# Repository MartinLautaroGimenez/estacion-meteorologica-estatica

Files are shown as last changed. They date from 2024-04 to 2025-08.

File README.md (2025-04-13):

# Estación Meteorológica Fija
## ¿Qué es una estación meteorológica?
Una estación meteorológica es un dispositivo tecnológico de características electrónica e informática que permite nuclear parámetros relevantes para realizar estudios y sacar conclusiones frente a fenómenos físicos.

## ¿Qué es E.M.F.?
Este es el inicio del proyecto EME, fue desarrollado en 2022 por el Alumno Nicolas Pérez de la escuela ETec UM, para posteriormente en el año 2024, tras el egreso de Nicolas de la escuela, la estación fue acogida por el taller Aeroglobe ETec y en conjunto con el nevo equipo que se creó en el taller se le pudo dar continuidad y agregar sensores y actualizar partes de la estación. 

## E.M.E.
Este es un proyecto institucional y surge de la necesidad de poder comprar los sistemas atmosféricos de algunos departamentos como Godoy Cruz, Gran Mendoza, Lavalle entre otros departamentos unidos a la red de la Escuela ETec de la Universidad de Mendoza para tener un conocimiento amplio de las condiciones atmosféricas de la provincia y así contribuir al análisis de las condiciones climáticas de la misma. Este es el nexo entre todas las estaciones y su finalidad es crear una red de nodos open surce en la cual podamos extraer datos para diferentes investigaciones o proyectos ya sean de la escuela o externos ya que los datos son públicos.  

## Los modulos incorporados
  - [ESP32](#ESP32)
  - [BMP180](#BMP180)
  - [DHT22](#DHT22)
  - [BMS 3S](#BMS-3S)
  - [Baterías 18650](#Baterías-18650)
  - [Panel Solar](#Panel-Solar)
  - [Sensor de Hoja Mojada](#Sensor-de-Hoja-Mojada)
  - [BH1750](#BH1750)
  - [MQ-135](#MQ-135)
  - [Veleta](#Veleta)
  - [Anemómetro](#Anemómetro)
 
### ESP32
#### DOIT ESP32 Devkit V1
La placa ESP32 (DOIT ESP32 Devkit V1) es un módulo basado en el microcontrolador ESP32, conocido por su capacidad de conexión Wi-Fi y Bluetooth. En nuestra estación meteorológica, esta placa desempeñará un papel vital al ofrecer una base solida para la  recopilación y transmisión de datos ambientales. Con su capacidad para manejar múltiples sensores y su compatibilidad con entornos de desarrollo como Arduino IDE, la ESP32 garantiza un funcionamiento continuo incluso en condiciones adversas, asegurando la integridad y precisión de las mediciones meteorológicas.

<div align="center">
   
</div>

### BMP180
El sensor BMP180 es un dispositivo el cual es utilizado para medir la presión atmosférica y la altitud a nivel del mar con un alto nivel de precisión. Es conocido por su pequeño tamaño y por su simplicidad al momento de realizar mediciones. 

<div align="center">
   
</div>

### DHT22
El sensor DHT22 es un componente crucial en el campo de la electrónica y la monitorización ambiental. 
Su función principal es medir con precisión la temperatura ambiente y la humedad relativa del entorno en el que se encuentra la estación meteorológica. Este sensor incorpora un termistor para la medición de la temperatura y un elemento especializado para medir la humedad relativa.

<div align="center">
   
</div>

### BMS 3S
El módulo BMS 3S es esencial para la carga de las baterías, ya que desempeña un papel crucial en la regulación del voltaje que reciben durante el proceso de carga. Este módulo garantiza que las baterías reciban el voltaje adecuado para una carga segura y eficiente.

<div align="center">
   
</div>

### Baterías 18650
Las baterías 18650 son células recargables de iones de litio conocidas por su alta densidad de energía y fiabilidad. En nuestra estación meteorológica, estas baterías desempeñarán un papel vital al ofrecer una fuente de alimentación constante y duradera, lo que garantizará un funcionamiento continuo incluso en condiciones adversas en las que el panel solar no pueda suministrar la potencia nominal.

<div align="center">
   
</div>

### Panel Solar
El panel solar le da la capacidad de poder estar lejos en un sector en donde no sea posible el tendido eléctrico para la alimentación de la EME, además brinda una opción de energía sustentable y limpia, reduciendo así el consumo eléctrico convencional que mayoritariamente proviene de centrales térmicas.
Además el mismo se le incorpora un pequeño módulo regulador de tensión para poder adaptar los niveles de tensión requeridos para la lógica del microcontrolador.

<div align="center">
   
</div>

### Sensor de Hoja Mojada
El sensor de hoja mojada permite tomar cómo parámetro el estado de la planta en cuanto a la generación de microorganismos que se presenten en la planta, de está manera se puede regular la aplicación de insecticida sin sobredosificar y ahorrando cantidades del mismo, si el mismo fuese aplicado a calendario. Además permite tener un mejor control en cuanto a la biodiversidad de los demás microorganismos que puedan aparecer en la planta que no sean dañinos. 

<div align="center">
   
</div>

### BH1750
El sensor BH1750 es un sensor el cual está diseñado para medir la intensidad de la luz de manera precisa. Es altamente valorado por su facilidad de uso y su capacidad de obtener lecturas rápidas en una amplia variedad de ambientes. Su pequeño tamaño y alta precisión lo hacen el más querido de los sensores de luz.

<div align="center">
   
</div>

### MQ-135
El sensor MQ135 es un componente el cual permite detectar gases nocivos para el aire, como el amoníaco, sulfuro de hidrógeno, dióxido de carbono, y otros compuestos orgánicos volátiles. Es conocido por la capacidad de proporcionar alertas tempranas sobre la presencia de estos gases.
De este sensor podemos tomar datos analógicos del comportamiento de la mezcla de gases y la capacidad de marcar un umbral de disparo para una salida digital de ser requerida, para ello es necesario acceder manualmente al trimmer de su pcb y calibrar el disparo del mismo

<div align="center">
   
</div>

### Veleta
Permite tomar la dirección actual del viento discretizando dicha dirección en 8 posiciones cardinales gracias a su forma constructiva, un imán de neodimio y 8 reed switch.

<div align="center">
     
</div>

### Anemómetro 
Para el anemómetro se requiere tanto de la parte física como del módulo o sensor de efecto hall que es quien detecta cada revolución de giro y la envía a una etapa amplificadora para poder contar cada pulso entrante 

<div align="center">
    
</div>

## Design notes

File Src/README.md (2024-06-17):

# Código Fuente (SRC)

Parte encargada del funcionamiento del sistema embebido que es la estación meteorológica estática (EME) de por si, en donde se ha optado por usar un ESP32 en su placa de desarrollo DOIT ESP32 DevKit V1 programando en el entorno de VSCode con el plugin de PlatformIO y haciendo uso del framework de Arduino para su programación

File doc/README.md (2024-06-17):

# Documentación 

Apartado para el agregado de documentación pertinente tales cómo, informe técnico, hojas de datos relevantes, manual de uso del proyecto, flyer paso a paso de su uso o similares.

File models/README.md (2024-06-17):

# Modelos 3D

Actualmente se trabajado con SolidWorks y Fusion360 para el diseño de los mismos. Además de considerar modelos ya existentes en la red de Thingiverse de la cual nos hemos basado.

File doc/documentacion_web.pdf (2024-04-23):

# EME

# DOCUMENTACIÓN

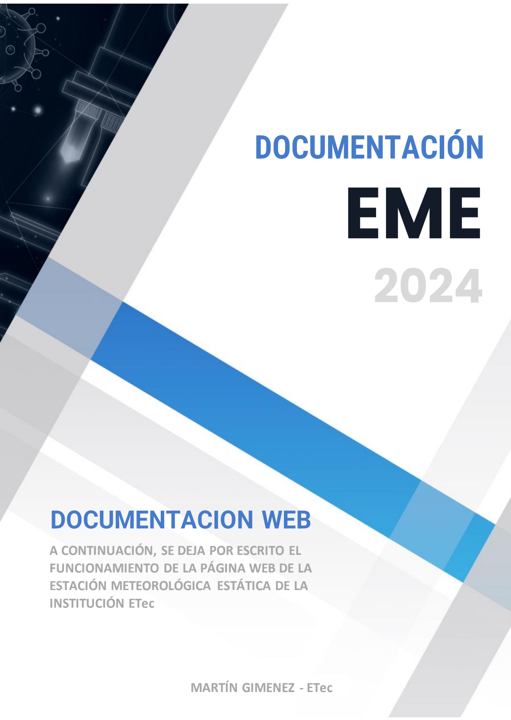
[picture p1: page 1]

# DOCUMENTACION WEB

### A CONTINUACIÓN, SE DEJA POR ESCRITO EL FUNCIONAMIENTO DE LA PÁGINA WEB DE LA ESTACIÓN METEOROLÓGICA ESTÁTICA DE LA INSTITUCIÓN ETec

2024

### MARTÍN GIMENEZ - ETec

El proyecto consiste en una aplicación web de una estación meteorológica que consta de tres archivos principales: index.html, style.css y app.js. A continuación se detalla el funcionamiento y los principios básicos de cada uno.
Index.html
El archivo index.html es la página principal de la aplicación. A continuación se describe su contenido y funcionalidad:
- Doctype y etiquetas HTML: El documento comienza con la declaración ‘<!DOCTYPE html>’ que es una instrucción para el navegador web sobre la versión de HTML que el documento está usando. Luego, el documento HTML se envuelve con la etiqueta <html> y se especifica el idioma del documento como español con el atributo lang="ES".
- Head: Dentro de la etiqueta <head>, se definen varios metadatos para el documento HTML. Esto incluye la codificación de caracteres, la configuración de la vista del puerto para dispositivos móviles, el título de la página y las referencias a los archivos de estilo CSS y a los iconos de la página.
- Body: El cuerpo del documento HTML contiene el contenido principal de la página web. Se divide en varias secciones:
- Sección de Datos Básicos: Esta sección muestra los datos meteorológicos básicos como la temperatura, la humedad, la presión atmosférica y la última actualización. Los datos se actualizan dinámicamente utilizando JavaScript.
- Tabla de Datos: Esta tabla muestra una lista de lecturas meteorológicas recientes. Los datos se insertan dinámicamente en la tabla utilizando JavaScript.
- Gráfico: Esta sección contiene un elemento de canvas para un gráfico para visualizar los datos meteorológicos y botones para ajustar la escala del gráfico.
- Pie de página: El pie de página contiene notas y descriptores sobre el proyecto, así como enlaces a la página de GitHub del proyecto y a una función para exportar los datos a Excel.
- JavaScript: Al final del cuerpo del documento, hay un bloque de código JavaScript que utiliza la API Fetch para obtener los últimos datos meteorológicos de un servidor local en http://localhost:3000/ultimos-datos. Los datos obtenidos se utilizan para actualizar el contenido de la página y para insertar filas en la tabla de datos.
STYLE.CSS
Brevemente explicando el funcionamiento de este archivo es el encargado de brindarle los estilos de la página web a index.html

APP.JS
Introducción
El archivo `app.js` es un script de Node.js que utiliza el marco de trabajo Express.js para crear un servidor web. Este servidor se conecta a una base de datos MySQL y proporciona una interfaz de API para interactuar con los datos. También utiliza el middleware CORS para permitir solicitudes de origen cruzado.
Importación de módulos

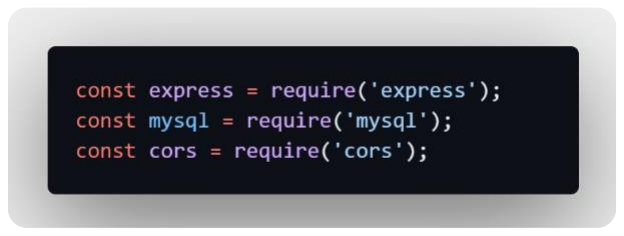
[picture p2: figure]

El script comienza importando los módulos necesarios. `express` es un marco de trabajo para crear servidores web en Node.js, `mysql` es un módulo para interactuar con bases de datos MySQL y `cors` es un middleware para habilitar CORS (Cross-Origin Resource Sharing).

Creación de la aplicación Express

Aquí se crea una nueva aplicación Express.

Configuración de la base de datos

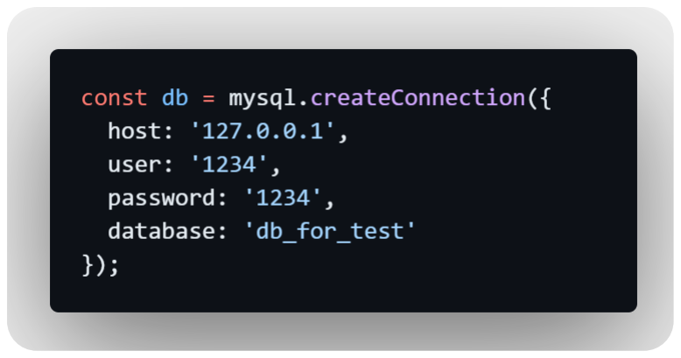
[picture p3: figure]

Se crea una conexión a la base de datos MySQL utilizando el método `createConnection` del módulo `mysql`. Los detalles de la conexión se proporcionan como un objeto.

Conexión a la base de datos

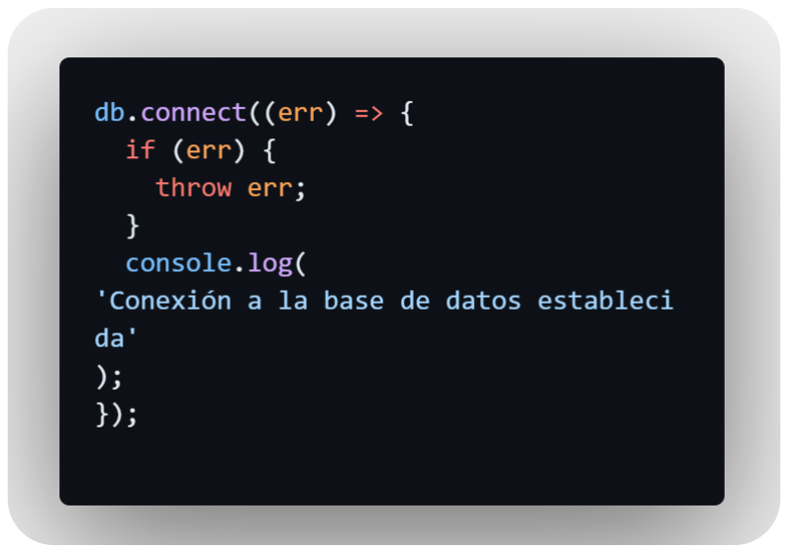
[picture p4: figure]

Se establece la conexión a la base de datos. Si hay un error durante la conexión, se lanzará una excepción.

Configuración de CORS

Se configura el middleware CORS en la aplicación Express para permitir solicitudes de origen cruzado.

Rutas de la API

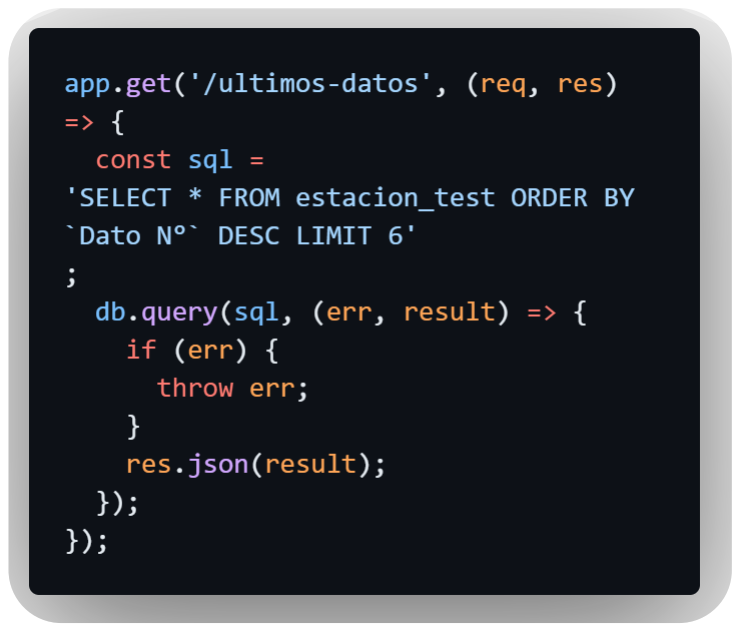
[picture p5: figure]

Se define una ruta de API para obtener los últimos datos de la base de datos. La consulta SQL selecciona los últimos 6 registros de la tabla `estacion_test`.

Servir archivos estáticos

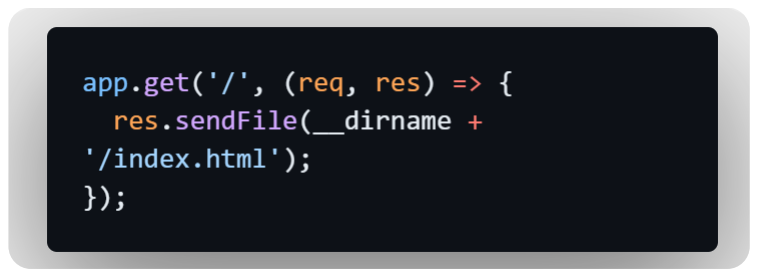
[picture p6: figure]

Se define una ruta para servir el archivo `index.html` cuando se accede a la raíz del servidor.

Inicio del servidor

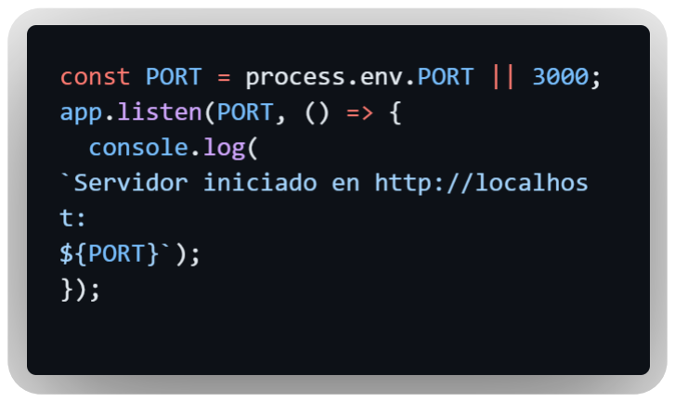
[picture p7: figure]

Finalmente, el servidor se inicia en el puerto especificado por la variable de entorno `PORT` o, si no está definida, en el puerto 3000.
CONCLUSIÓN

La documentación proporcionada detalla de manera clara y concisa el funcionamiento y los principios básicos del proyecto de la estación meteorológica. Desde la estructura de los archivos principales hasta los detalles de implementación en app.js, cada componente está explicado con suficiente detalle para comprender su propósito y funcionamiento.
La inclusión de imágenes ilustrativas mejora aún más la comprensión visual de la estructura del proyecto y la relación entre sus componentes. Esto facilita tanto el entendimiento inicial del proyecto como su mantenimiento continuo y la realización de contribuciones por parte de otros desarrolladores.
En resumen, la documentación proporcionada sirve como una guía completa y accesible para cualquier persona interesada en comprender, utilizar o contribuir al proyecto de la estación meteorológica.

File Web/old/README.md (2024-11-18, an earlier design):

# WEB DEVELOP

## Funcionalidades
La idea de poder tener una estación operativa que pueda leer datos es buena idea, pero si no son accesibles, dificílmente puedan ser aprobechables, por lo que se piensa armar una interfaz de usuario (Dashboard) capaz de poder proveer de dichos datos de interes a quienes lo soliciten o corresponda.

## ¿Qué se tiene en EMETec?
Cómo se ha visto un poco sobre la idea anteriormente, se proveeran datos de humedad relativa, temperatura absoluta, sensación térmica, temperatura punto de rocio, presión absoluta, presión a nivel de mar, altitud, intensidad luminica, valocidad del viento, dirección del mismo, calidad de aire, partes por millón de CO2, humedad de suelo y lluvia entre otros posibles datos de interes que vayan agregandosé en cada actualización.
<div align="center">
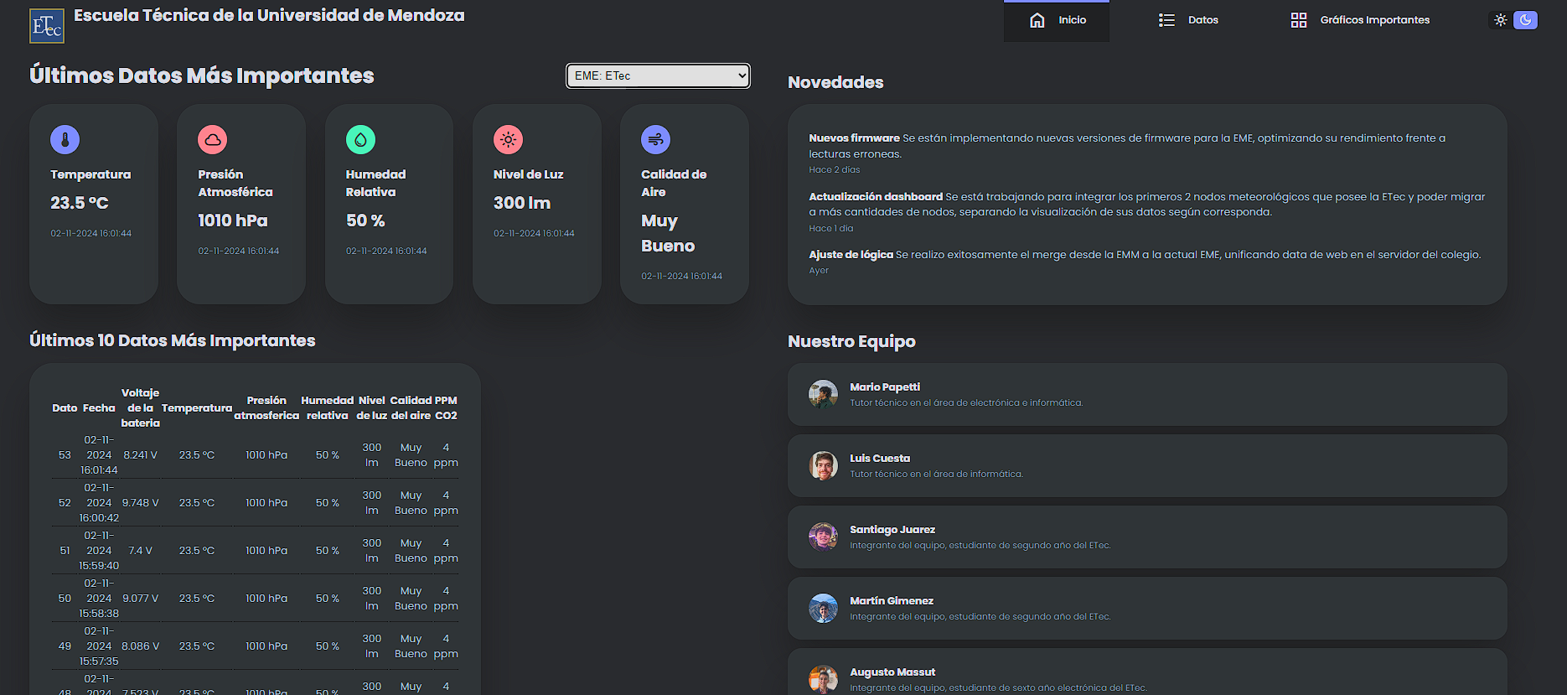
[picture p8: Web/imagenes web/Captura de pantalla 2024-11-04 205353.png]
   
</div>
## Las partes del Dashboard

  - [Dashboard](#Dashboard)
  - [Datos](#Datos)
  - [Gráficos](#Gráficos)
  - [Información](#Información)

### Dashboard
#### Dashboard Principal
El Dashboard Principal muestra una visión general de todos los datos recolectados por la estación meteorológica. Aquí, los usuarios pueden ver gráficos en tiempo real de las mediciones actuales, así como acceder a datos históricos. La interfaz está diseñada para ser intuitiva y fácil de usar, permitiendo a los usuarios personalizar las vistas según sus necesidades específicas. Además, se incluyen alertas y notificaciones para eventos meteorológicos importantes, asegurando que los usuarios estén siempre informados de las condiciones climáticas relevantes.

### Datos
#### Datos en Tiempo Real
En esta sección, los usuarios pueden acceder a los últimos datos proporcionados por la estación meteorológica. Los datos se actualizan cada 15 minutos para reflejar las condiciones actuales. Los usuarios pueden ver información detallada sobre cada parámetro medido, como temperatura, humedad, presión, y más.

#### Exportación de Datos
Los usuarios tienen la opción de exportar los datos en formato XLSX (Microsoft Excel), para su análisis externo. Esta funcionalidad permite a los usuarios integrar los datos de la estación meteorológica con otras herramientas y plataformas de análisis de datos.

### Gráficos
Sección que se lanzará proximamente.
#### Gráficos Personalizados
Esta sección permitirá a los usuarios crear gráficos personalizados basados en los datos recolectados por la estación meteorológica. Los usuarios podrán seleccionar los parámetros que desean visualizar y ajustar el rango de fechas para analizar tendencias específicas. Esta funcionalidad estará disponible próximamente.

#### Gráficos Comparativos
Próximamente, los usuarios podrán comparar diferentes parámetros meteorológicos en un solo gráfico. Esta herramienta será útil para identificar correlaciones y patrones entre variables como temperatura, humedad y presión.

#### Descarga de Gráficos
En una futura actualización, se habilitará la opción de descargar los gráficos en varios formatos (PNG, JPEG, PDF) para su uso en informes y presentaciones.

### Información
Proximamente

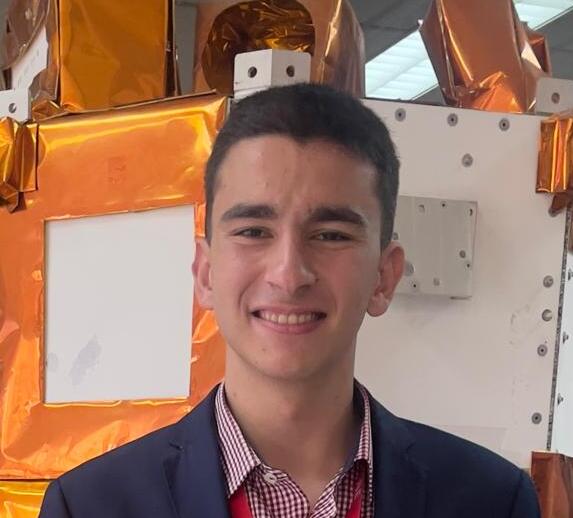
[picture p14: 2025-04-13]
Web/frontend/images/team/augusto.jpg

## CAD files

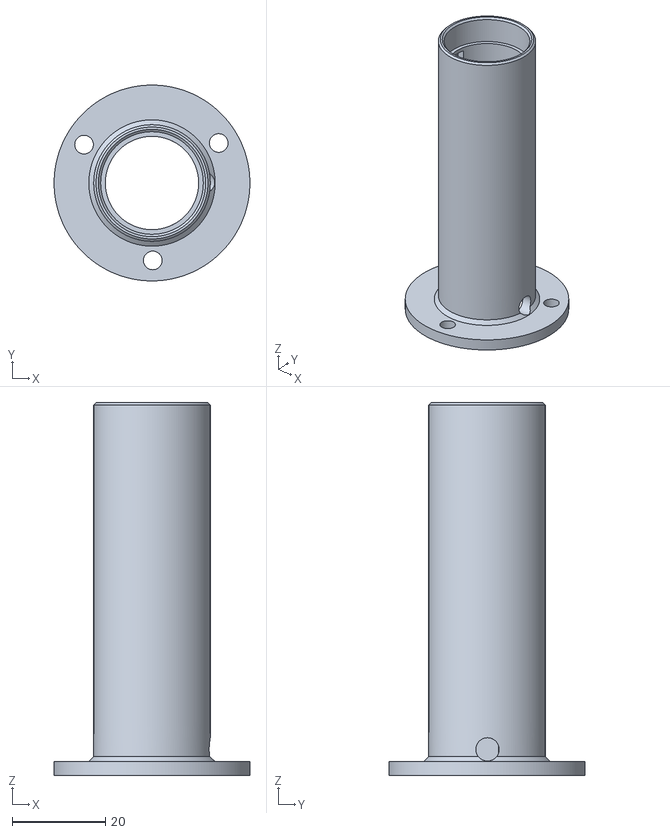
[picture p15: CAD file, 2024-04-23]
models/Anemometer/files/tower.stl
42.0 x 42.0 x 80.0

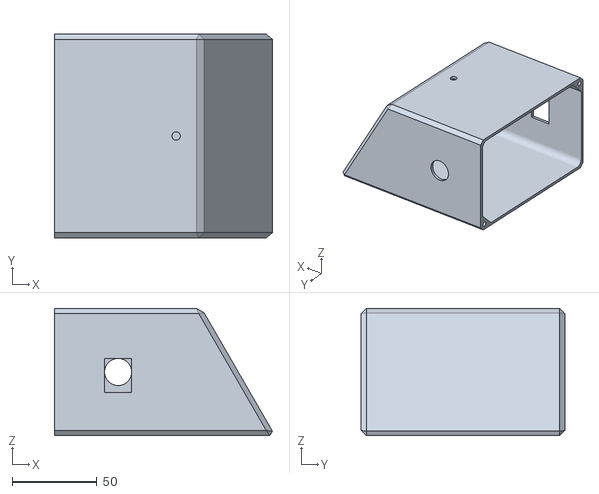
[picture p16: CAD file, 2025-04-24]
models/Estructuras/estacionMeteorologica v3.stl
128.5 x 120.0 x 75.0

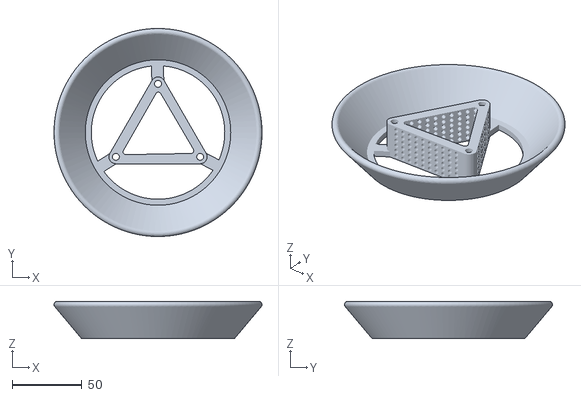
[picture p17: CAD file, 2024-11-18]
models/Gaseta/gaseta EMF medio v7.stl
149.6 x 149.6 x 26.8

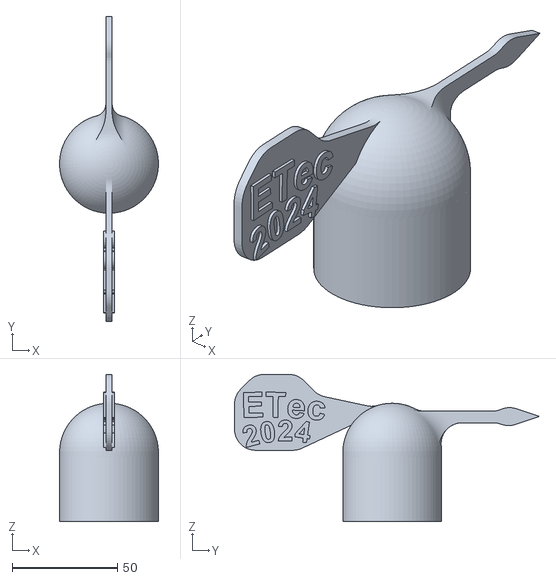
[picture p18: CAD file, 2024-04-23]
models/Veleta/TapaVeleta v1.stl
47.0 x 145.0 x 70.0

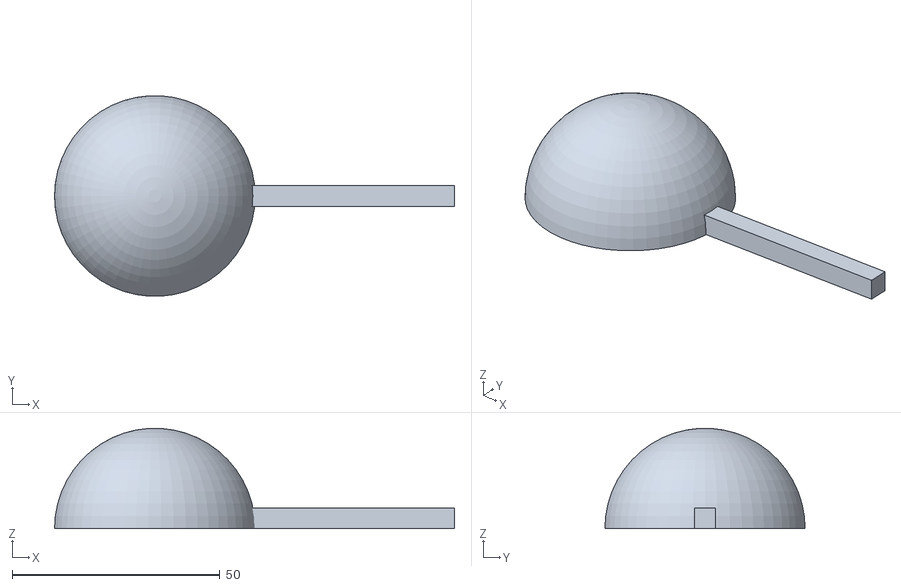
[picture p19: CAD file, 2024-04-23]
models/Anemometer/files/cup.stl
96.3 x 48.2 x 24.1

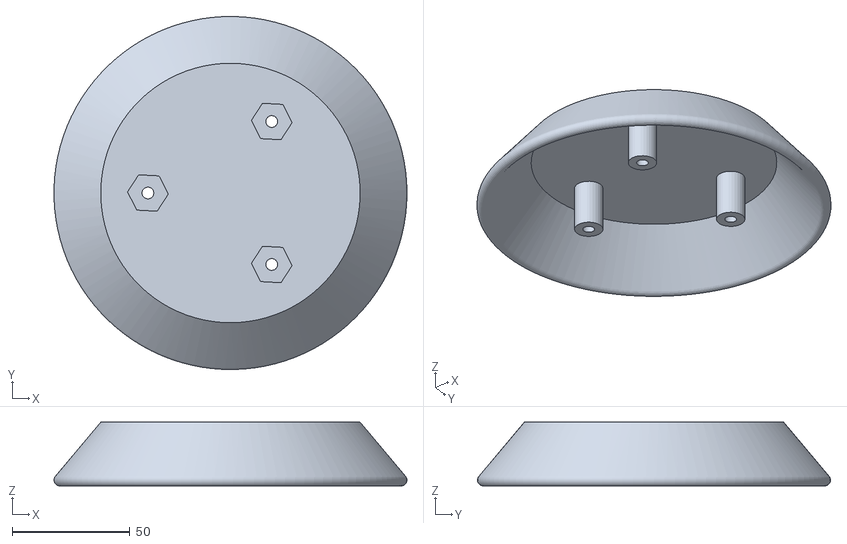
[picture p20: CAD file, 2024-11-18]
models/Gaseta/gaseta EMF tapa v7.stl
149.7 x 149.7 x 27.0

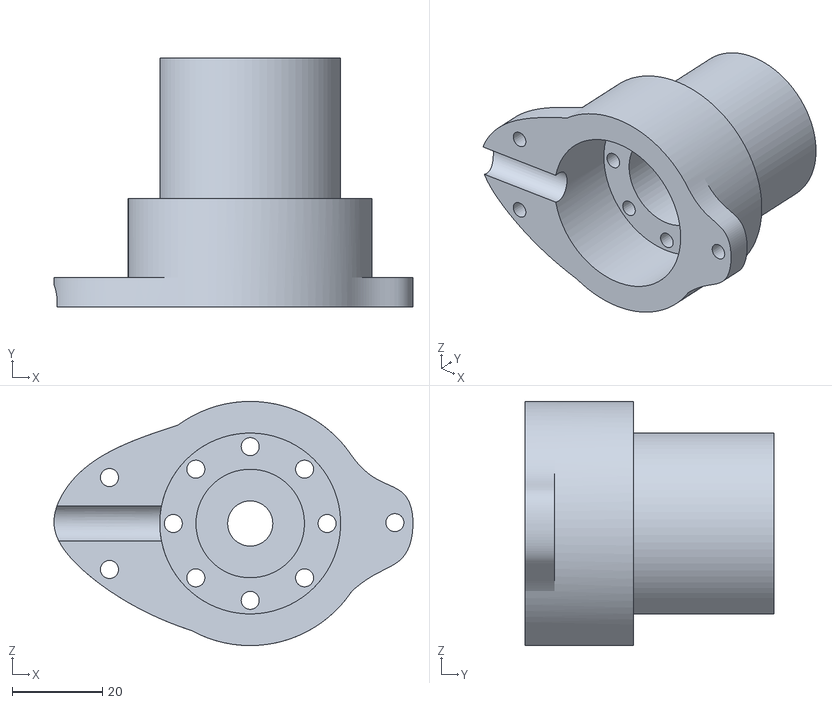
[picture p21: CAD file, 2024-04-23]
models/Veleta/BaseVeleta v1.stl
79.4 x 55.0 x 54.0

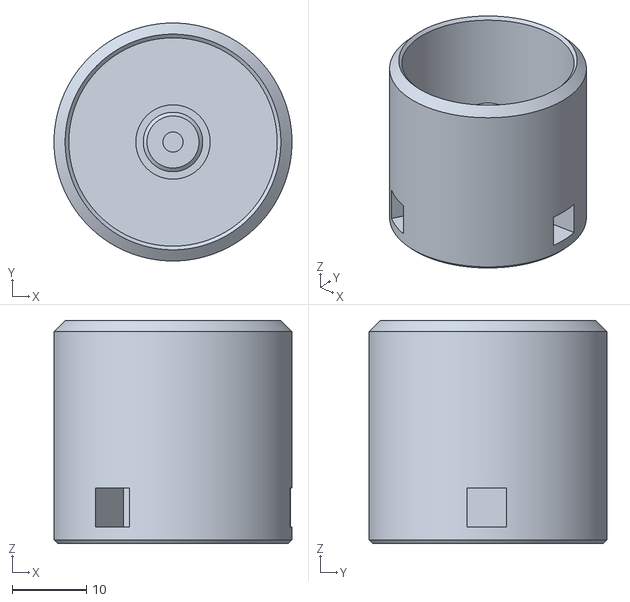
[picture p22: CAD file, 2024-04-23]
models/Anemometer/files/cover.stl
32.0 x 32.0 x 30.0

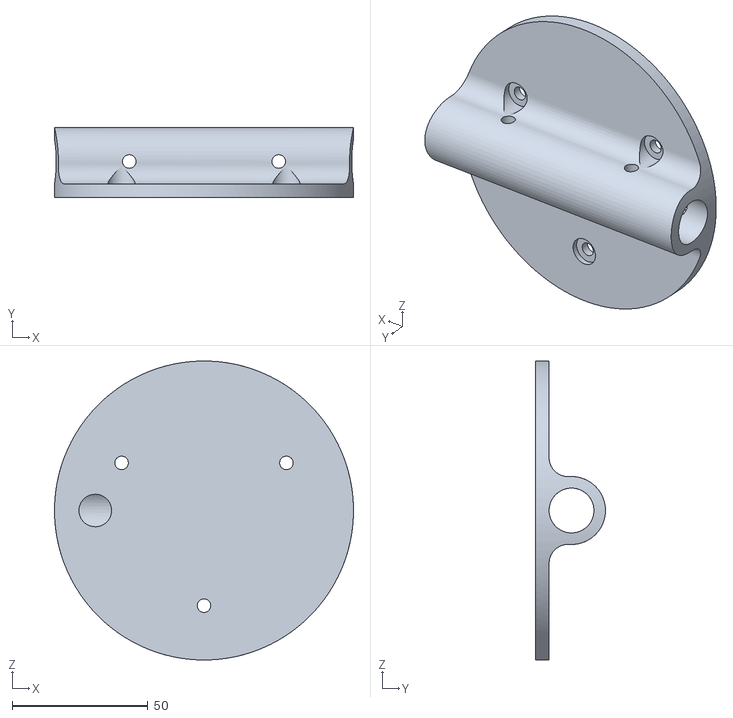
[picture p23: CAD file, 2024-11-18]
models/Gaseta/gaseta EMF platina v9.stl
110.0 x 25.8 x 110.0

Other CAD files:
models/Gaseta/gaseta EMF medio v7.f3d
models/Gaseta/gaseta EMF platina v9.f3d
models/Gaseta/gaseta EMF tapa v7.f3d
models/Veleta/BaseVeleta v1.f3d
models/Veleta/TapaVeleta v1.f3d

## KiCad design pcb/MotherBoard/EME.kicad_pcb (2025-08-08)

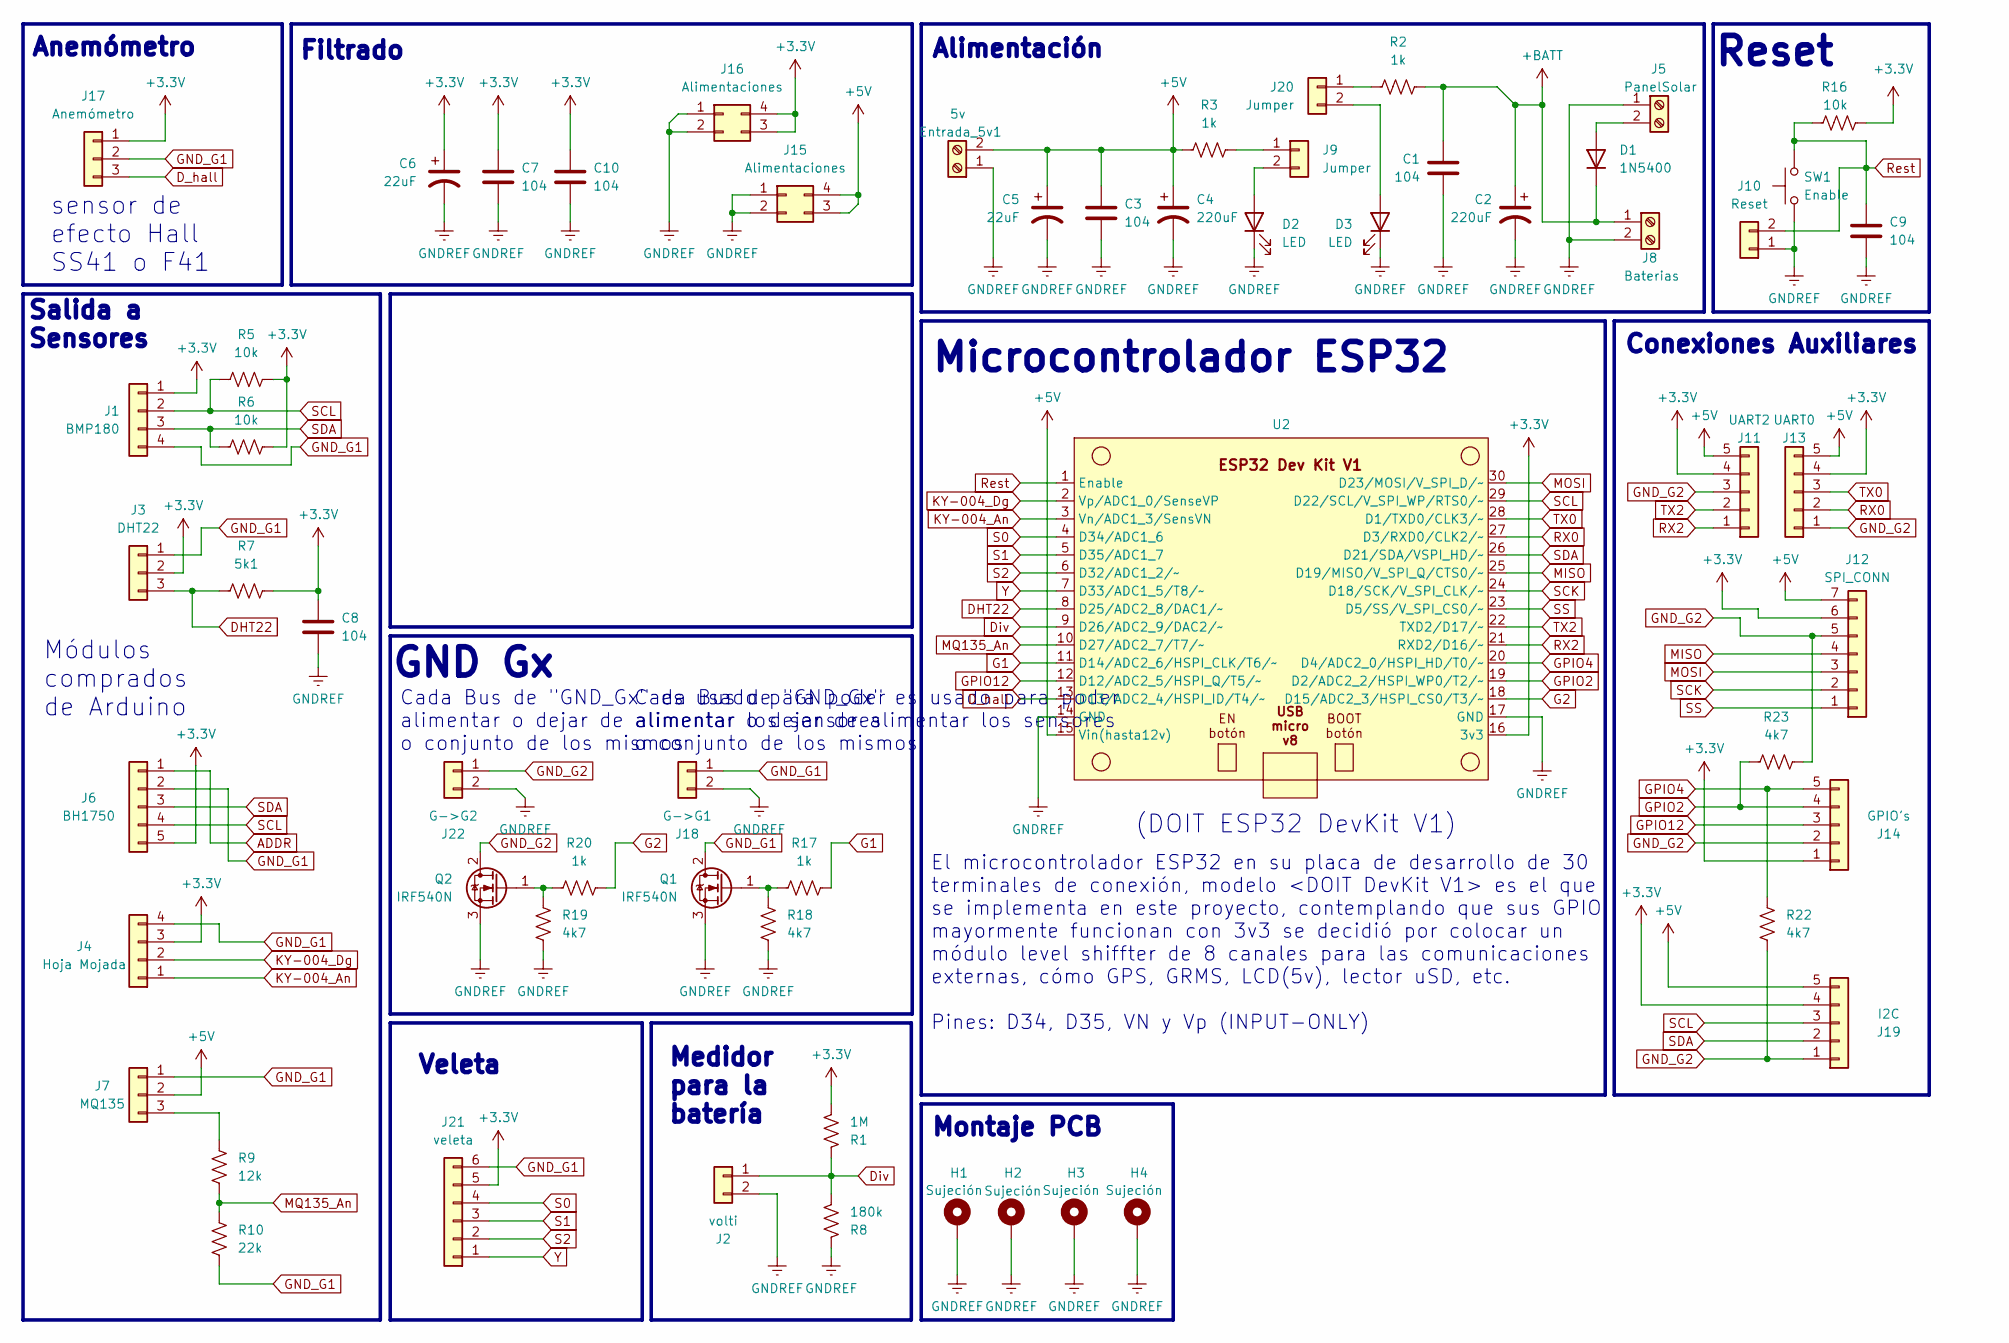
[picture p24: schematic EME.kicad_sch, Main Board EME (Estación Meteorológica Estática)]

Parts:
C1, C3, C7, C10: 104; C_Disc_D7.0mm_W2.5mm_P5.00mm
C2, C4: 220uF; C_Radial_D8.0mm_H11.5mm_P3.50mm
C5, C6: 22uF; C_Radial_D8.0mm_H7.0mm_P3.50mm
C8: 104; C_Disc_D7.5mm_W4.4mm_P5.00mm
C9: 104; C_Disc_D4.3mm_W1.9mm_P5.00mm
D1: 1N5400; D_DO-201AD_P15.24mm_Horizontal
D2, D3: LED; LED_D5.0mm_Clear
Entrada_5v1: 5v; TerminalBlock_Phoenix_PT-1,5-2-5.0-H_1x02_P5.00mm_Horizontal
H1, H2, H3, H4: Sujeción; MountingHole_3.5mm_Pad
J1: BMP180; PinHeader_1x04_P2.54mm_Vertical
J2: volti; PinHeader_1x02_P2.54mm_Vertical
J3: DHT22; PinHeader_1x03_P2.54mm_Vertical
J4: Hoja Mojada; PinHeader_1x04_P2.54mm_Vertical
J5: PanelSolar; TerminalBlock_Phoenix_PT-1,5-2-5.0-H_1x02_P5.00mm_Horizontal
J6: BH1750; PinHeader_1x05_P2.54mm_Vertical
J7: MQ135; PinHeader_1x03_P2.54mm_Vertical
J8: Baterias; TerminalBlock_Phoenix_PT-1,5-2-5.0-H_1x02_P5.00mm_Horizontal
J9, J20: Jumper; PinHeader_1x02_P2.54mm_Vertical
J10: Reset; PinHeader_1x02_P2.54mm_Vertical
J11: UART2; PinHeader_1x05_P2.54mm_Vertical
J12: SPI_CONN; PinHeader_1x07_P2.54mm_Vertical
J13: UART0; PinHeader_1x05_P2.54mm_Vertical
J14: GPIO's; PinHeader_1x05_P2.54mm_Vertical
J15, J16: Alimentaciones; PinHeader_2x02_P2.54mm_Vertical
J17: Anemómetro; PinHeader_1x03_P2.54mm_Vertical
J18: G->G1; PinHeader_1x02_P2.54mm_Vertical
J19: I2C; PinHeader_1x05_P2.54mm_Vertical
J21: veleta; PinHeader_1x06_P2.54mm_Vertical
J22: G->G2; PinHeader_1x02_P2.54mm_Vertical
Q1, Q2: IRF540N; TO-220-3_Vertical
R1: 1M; R_Axial_DIN0207_L6.3mm_D2.5mm_P10.16mm_Horizontal
R2, R3, R17, R20: 1k; R_Axial_DIN0207_L6.3mm_D2.5mm_P10.16mm_Horizontal
R5, R6, R16: 10k; R_Axial_DIN0207_L6.3mm_D2.5mm_P10.16mm_Horizontal
R7: 5k1; R_Axial_DIN0207_L6.3mm_D2.5mm_P10.16mm_Horizontal
R8: 180k; R_Axial_DIN0207_L6.3mm_D2.5mm_P10.16mm_Horizontal
R9: 12k; R_Axial_DIN0207_L6.3mm_D2.5mm_P10.16mm_Horizontal
R10: 22k; R_Axial_DIN0207_L6.3mm_D2.5mm_P10.16mm_Horizontal
R18, R19, R22, R23: 4k7; R_Axial_DIN0207_L6.3mm_D2.5mm_P10.16mm_Horizontal
SW1: Enable; SW_PUSH_6mm_H8mm
U2: ESP32-DevKit_V1

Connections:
+3.3V: C6.1, C7.1, C8.1, C10.1, J1.1, J3.2, J4.3, J6.5, J11.4, J12.6, J13.4, J14.1, J16.3, J16.4, J17.1, J19.4, J21.5, R1.1, R5.2, R6.2, R7.2, R16.2, U2.16 (3v3); also elsewhere on the board
+5V: C3.1, C4.1, C5.1, Entrada_5v1.2, J7.2, J11.5, J12.7, J13.5, J15.3, J15.4, J19.5, R3.1, U2.15 (Vin(hasta12v))
+BATT: C1.1, C2.1, D1.1 (K), J8.1, R2.2
ADDR: J6.1
DHT22: J3.3, R7.1, U2.8 (D25/ADC2_8/DAC1/~)
D_hall: J17.3, U2.13 (D13/ADC2_4/HSPI_ID/T4/~)
Div: J2.1, R1.2, R8.1, U2.9 (D26/ADC2_9/DAC2/~)
G1: R17.2, U2.11 (D14/ADC2_6/HSPI_CLK/T6/~)
G2: R20.2, U2.18 (D15/ADC2_3/HSPI_CS0/T3/~)
GNDREF: C1.2, C2.2, C3.2, C4.2, C5.2, C6.2, C7.2, C8.2, C9.2, C10.2, D2.1 (K), D3.1 (K), Entrada_5v1.1, H1.1, H2.1, H3.1, H4.1, J2.2, J5.1, J8.2, J10.1, J15.1, J15.2, J16.1, J16.2, J18.2, J22.2, Q1.3 (S), Q2.3 (S), R8.2, R18.1, R19.1, SW1.1, U2.14 (GND), U2.17 (GND); also elsewhere on the board
GND_G1: J1.4, J3.1, J4.4, J6.2, J7.1, J17.2, J18.1, J21.6, Q1.2 (D), R10.1
GND_G2: J11.3, J12.5, J13.1, J14.2, J19.1, J22.1, Q2.2 (D), R22.1, R23.1
GPIO2: J14.4, R23.2, U2.19 (D2/ADC2_2/HSPI_WP0/T2/~)
GPIO4: J14.5, R22.2, U2.20 (D4/ADC2_0/HSPI_HD/T0/~)
GPIO12: J14.3, U2.12 (D12/ADC2_5/HSPI_Q/T5/~)
KY-004_An: J4.1, U2.3 (Vn/ADC1_3/SensVN)
KY-004_Dg: J4.2, U2.2 (Vp/ADC1_0/SenseVP)
MISO: J12.4, U2.25 (D19/MISO/V_SPI_Q/CTS0/~)
MOSI: J12.3, U2.30 (D23/MOSI/V_SPI_D/~)
MQ135_An: R9.1, R10.2, U2.10 (D27/ADC2_7/T7/~)
unnamed: D1.2 (A), J5.2
unnamed: D2.2 (A), J9.2
unnamed: D3.2 (A), J20.2
unnamed: J7.3, R9.2
unnamed: J9.1, R3.2
unnamed: J20.1, R2.1
unnamed: Q1.1 (G), R17.1, R18.2
unnamed: Q2.1 (G), R19.2, R20.1
RX0: J13.2, U2.27 (D3/RXD0/CLK2/~)
RX2: J11.1, U2.21 (RXD2/D16/~)
Rest: C9.1, J10.2, R16.1, SW1.2, U2.1 (Enable)
S0: J21.4, U2.4 (D34/ADC1_6)
S1: J21.3, U2.5 (D35/ADC1_7)
S2: J21.2, U2.6 (D32/ADC1_2/~)
SCK: J12.2, U2.24 (D18/SCK/V_SPI_CLK/~)
SCL: J1.2, J6.4, J19.3, R5.1, U2.29 (D22/SCL/V_SPI_WP/RTS0/~)
SDA: J1.3, J6.3, J19.2, R6.1, U2.26 (D21/SDA/VSPI_HD/~)
SS: J12.1, U2.23 (D5/SS/V_SPI_CS0/~)
TX0: J13.3, U2.28 (D1/TXD0/CLK3/~)
TX2: J11.2, U2.22 (TXD2/D17/~)
Y: J21.1, U2.7 (D33/ADC1_5/T8/~)

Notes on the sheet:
Cada Bus de "GND_Gx" es usado para poder alimentar o dejar de alimentar los sensores o conjunto de los mismos
Salida a Sensores
GND Gx
Anemómetro
sensor de efecto Hall SS41 o F41
El microcontrolador ESP32 en su placa de desarrollo de 30 terminales de conexión, modelo <DOIT DevKit V1> es el que se implementa en este proyecto, contemplando que sus GPIO mayormente funcionan con 3v3 se decidió por colocar un módulo level shiffter de 8 canales para las comunicaciones externas, c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
Microcontrolador ESP32
Medidor para la batería
Veleta
Módulos comprados de Arduino
Reset
Alimentación
Montaje PCB
Filtrado
(DOIT ESP32 DevKit V1)
Conexiones Auxiliares

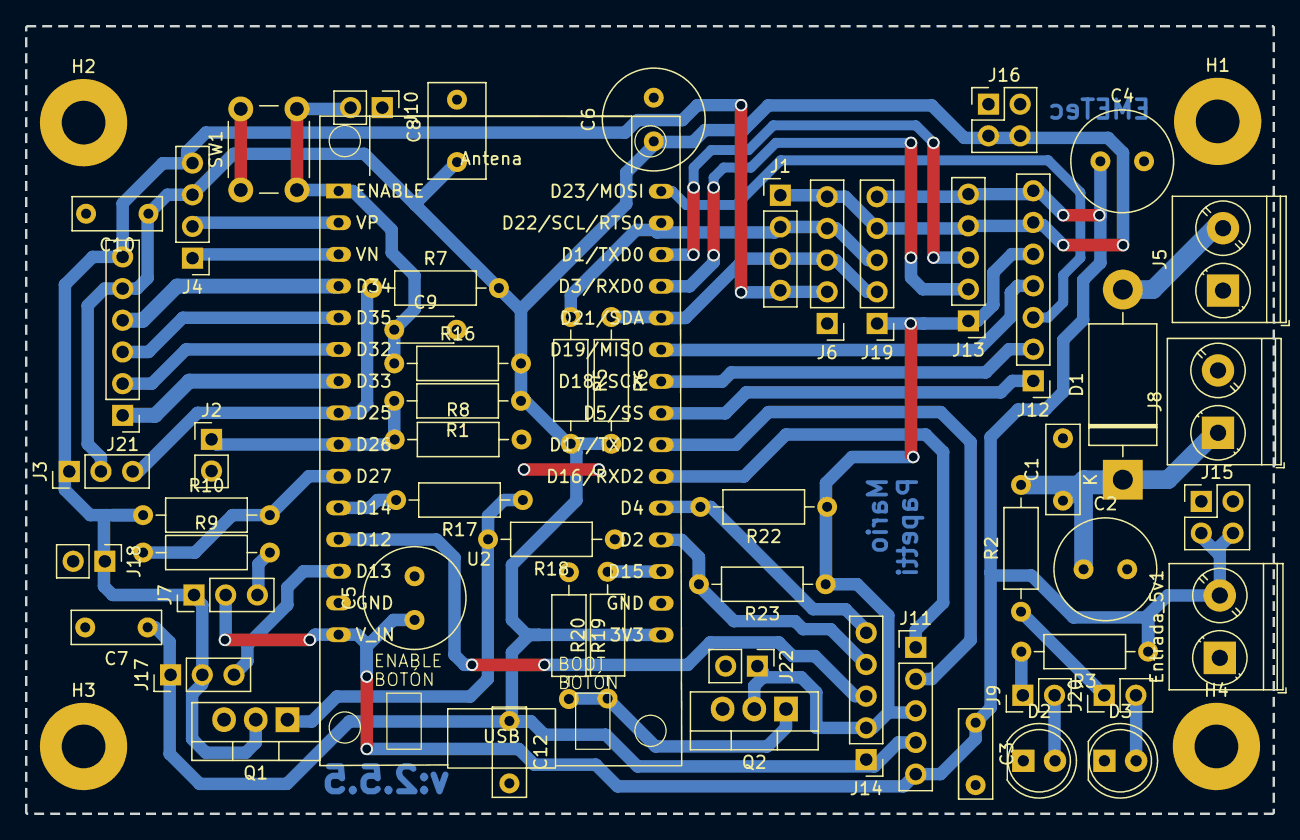
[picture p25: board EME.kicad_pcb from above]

Board: 2 copper layers, 100.0 x 63.1 mm, 61 parts (0 on the bottom side), 40 nets.

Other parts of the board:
C12: 104; C_Disc_D7.0mm_W2.5mm_P5.00mm

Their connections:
+3.3V: C12.1; also elsewhere on the board
GNDREF: C12.2; also elsewhere on the board

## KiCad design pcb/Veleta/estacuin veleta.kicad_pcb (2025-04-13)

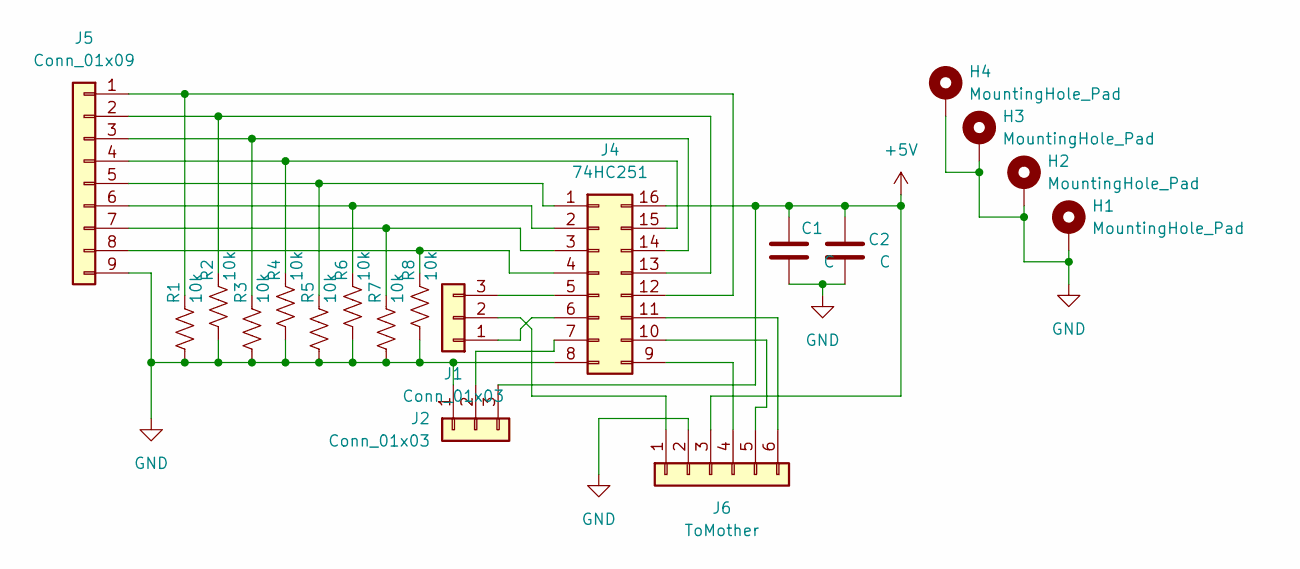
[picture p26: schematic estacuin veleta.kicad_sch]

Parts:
C1, C2: C; C_Radial_D6.3mm_H7.0mm_P2.50mm
H1, H2, H3, H4: MountingHole_Pad; MountingHole_2.2mm_M2_DIN965_Pad
J1, J2: Conn_01x03; PinHeader_1x03_P2.54mm_Vertical
J4: 74HC251; DIP-16_W7.62mm
J5: Conn_01x09; PinSocket_1x09_P2.54mm_Vertical
J6: ToMother; PinSocket_1x06_P2.54mm_Vertical
R1, R2, R3, R4, R5, R6, R7, R8: 10k; R_Axial_DIN0207_L6.3mm_D2.5mm_P10.16mm_Horizontal

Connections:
+5V: C1.1, C2.1, J2.3, J4.16, J6.3
GND: C1.2, C2.2, H1.1, H2.1, H3.1, H4.1, J2.1, J4.8, J5.9, J6.2, R1.2, R2.2, R3.2, R4.2, R5.2, R6.2, R7.2, R8.2
unnamed: J1.1, J4.6
unnamed: J1.2, J6.1
unnamed: J1.3, J4.5
unnamed: J2.2, J4.7
unnamed: J4.1, J5.5, R5.1
unnamed: J4.2, J5.6, R6.1
unnamed: J4.3, J5.7, R7.1
unnamed: J4.4, J5.8, R8.1
unnamed: J4.9, J6.4
unnamed: J4.10, J6.5
unnamed: J4.11, J6.6
unnamed: J4.12, J5.1, R1.1
unnamed: J4.13, J5.2, R2.1
unnamed: J4.14, J5.3, R3.1
unnamed: J4.15, J5.4, R4.1

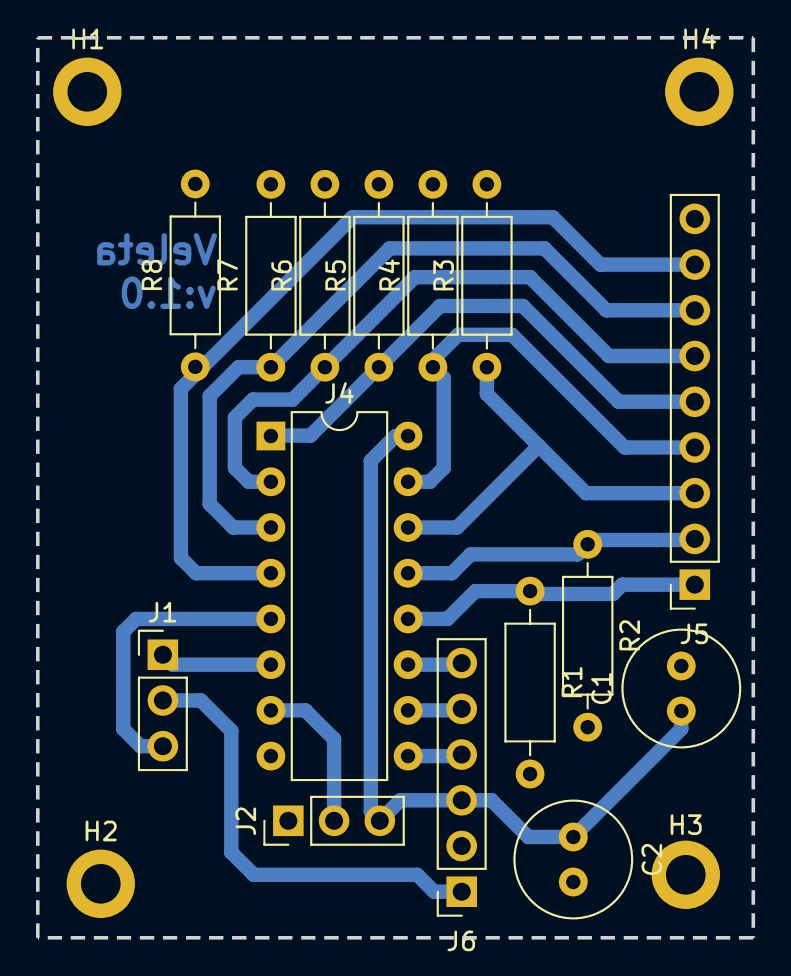
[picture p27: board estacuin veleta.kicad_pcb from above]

Board: 2 copper layers, 39.8 x 50.0 mm, 19 parts (0 on the bottom side), 17 nets.

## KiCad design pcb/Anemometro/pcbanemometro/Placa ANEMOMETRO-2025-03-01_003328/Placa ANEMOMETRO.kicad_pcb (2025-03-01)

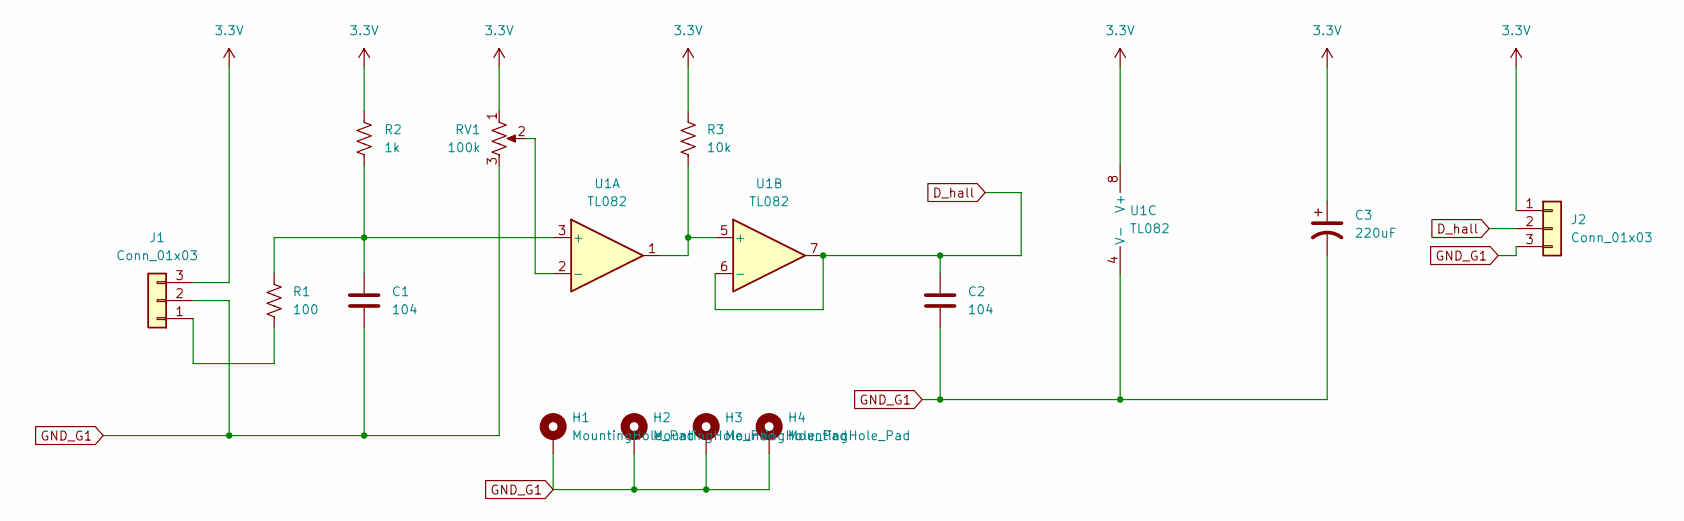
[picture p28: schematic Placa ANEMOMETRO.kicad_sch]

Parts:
C1, C2: 104; C_Disc_D4.3mm_W1.9mm_P5.00mm
C3: 220uF; C_Radial_D5.0mm_H7.0mm_P2.00mm
H1, H2, H3, H4: MountingHole_Pad; MountingHole_2.2mm_M2_DIN965_Pad
J1, J2: Conn_01x03; PinHeader_1x03_P2.54mm_Vertical
R1: 100; R_Axial_DIN0207_L6.3mm_D2.5mm_P7.62mm_Horizontal
R2: 1k; R_Axial_DIN0207_L6.3mm_D2.5mm_P7.62mm_Horizontal
R3: 10k; R_Axial_DIN0207_L6.3mm_D2.5mm_P7.62mm_Horizontal
RV1: 100k; Potentiometer_Bourns_3296Y_Vertical
U1: TL082; DIP-8_W7.62mm_Socket

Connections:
3.3V: C3.1, J1.3, J2.1, R2.1, R3.1, RV1.1, U1.8 (V+)
D_hall: C2.1, J2.2, U1.6 (-), U1.7
GND_G1: C1.2, C2.2, C3.2, H1.1, H2.1, H3.1, H4.1, J1.2, J2.3, RV1.3, U1.4 (V-)
unnamed: J1.1, R1.2
unnamed: C1.1, R1.1, R2.2, U1.3 (+)
unnamed: RV1.2, U1.2 (-)
unnamed: R3.2, U1.1, U1.5 (+)

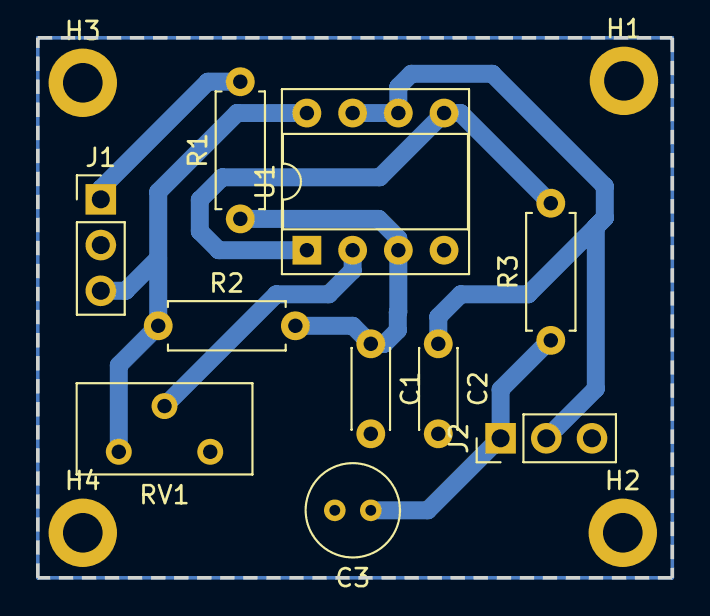
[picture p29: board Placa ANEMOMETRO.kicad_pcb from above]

Board: 2 copper layers, 35.2 x 30.0 mm, 14 parts (0 on the bottom side), 7 nets.

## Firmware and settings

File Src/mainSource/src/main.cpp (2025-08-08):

#include <Arduino.h>
#include <WiFi.h>
#include <WiFiClientSecure.h>
#include <Preferences.h>
#include <AsyncTCP.h>
#include <ESPAsyncWebServer.h>
#include <WebSerial.h>
#include <ESPmDNS.h>  // Para mDNS

// —— Añadidos para forzar hostname —— 
#include <esp_netif.h>
// ————————————————————————————————

#include "config.h"
#include "../lib/LeerSensores.h"

#ifdef USE_PANTALLA
  #include "../lib/pantallacontroller.h"
  PantallaController pantalla;
  unsigned long tiempoUltimaPantalla = 0;
  uint8_t indicePantalla = 0;
#endif

#ifdef ota
  #include <ArduinoOTA.h>
#endif

#ifdef WEBAPP
  #include "../lib/WebController.h"
#endif

WiFiClientSecure client;
LeerSensores sensores;
Preferences preferences;
AsyncWebServer server(2020); // Web server asincrónico

#ifdef WEBAPP
WebController webapp(80, &sensores, &preferences);
#endif

String jsonValue(float value) {
  return (isnan(value) || value < 0) ? "0" : String(value, 2);
}

void startCaptivePortal();
void handleCaptivePortal();

void conectarWiFi() {
  // Inicializa la interfaz de red y fuerza modo estación
  esp_netif_init();
  WiFi.mode(WIFI_STA);

  preferences.begin("wifi", true);
  String ssid = preferences.getString("ssid", "");
  String pass = preferences.getString("pass", "");
  preferences.end();

  if (ssid == "") {
    #ifdef RED_SSID_WIFI
      ssid = RED_SSID_WIFI;
      pass = PASSWORD_WIFI;
      Serial.println("Usando credenciales predeterminadas.");
      WebSerial.println("Usando credenciales predeterminadas.");
    #else
      Serial.println("❌ Sin credenciales y sin predeterminadas.");
      WebSerial.println("❌ Sin credenciales y sin predeterminadas.");
    #endif
  }

  if (ssid != "") {
    Serial.print("Conectando a: "); Serial.println(ssid);
    WebSerial.print("Conectando a: "); WebSerial.println(ssid);

    // —— Forzamos el hostname ANTES de conectar —— 
    esp_netif_t* sta_netif = esp_netif_get_handle_from_ifkey("WIFI_STA_DEF");
    esp_netif_set_hostname(sta_netif, hostdom);
    // ————————————————————————————————

    WiFi.begin(ssid.c_str(), pass.c_str());

    unsigned long startAttemptTime = millis();
    while (WiFi.status() != WL_CONNECTED && millis() - startAttemptTime < 10000) {
      delay(500); Serial.print("."); WebSerial.print(".");
    }
    Serial.println(); WebSerial.println();

    if (WiFi.status() == WL_CONNECTED) {
      String ip = WiFi.localIP().toString();
      Serial.println("✅ Conectado. IP: " + ip);
      WebSerial.println("✅ Conectado. IP: " + ip);
      digitalWrite(ledverde, HIGH);
      #ifdef USE_PANTALLA
        pantalla.mostrarEstadoWiFi(ssid, ip);
      #endif

      // —— Iniciar mDNS para "eme.local" y HTTP ——
      if (MDNS.begin(hostdom)) {
        MDNS.addService("http", "tcp", 80);
        Serial.println("✅ mDNS iniciado: http://" + String(hostdom) + ".local");
        WebSerial.println("✅ mDNS iniciado: http://" + String(hostdom) + ".local");
      } else {
        Serial.println("❌ Error iniciando mDNS");
        WebSerial.println("❌ Error iniciando mDNS");
      }
      // ——————————————————————————

    } else {
      Serial.println("❌ Falló conexión. Activando portal cautivo.");
      WebSerial.println("❌ Falló conexión. Activando portal cautivo.");
      String mac = WiFi.macAddress();
      Serial.println("MAC: " + mac);
      WebSerial.println("MAC: " + mac);
      #ifdef USE_PANTALLA
        pantalla.mostrarError("Config. wifi activo");
      #endif
      startCaptivePortal();
    }
  } else {
    Serial.println("📡 Sin credenciales. Activando portal cautivo.");
    WebSerial.println("📡 Sin credenciales. Activando portal cautivo.");
    #ifdef USE_PANTALLA
      pantalla.mostrarError("Config. wifi activo");
    #endif
    startCaptivePortal();
  }
}

void enviarDatos() {
  sensores.leerTodos();
  client.setInsecure();

  String postData = "{\"EME_n0/dht/temp\":" + jsonValue(sensores.tempDHT) + 
                    ",\"EME_n0/dht/hum\":"  + jsonValue(sensores.humDHT) + 
                    ",\"EME_n0/dht/senst\":"+ jsonValue(sensores.sensDHT) + 
                    ",\"EME_n0/bmp/temp\":"+ jsonValue(sensores.tempBMP) +
                    ",\"EME_n0/bmp/pres\":"+ jsonValue(sensores.presBMP) +
                    ",\"EME_n0/bmp/alt\":" + jsonValue(sensores.altBMP) +
                    ",\"EME_n0/bmp/presnm\":"+ jsonValue(sensores.presNMBMP) +
                    ",\"EME_n0/bh/luz\":" + jsonValue(sensores.bh1750) +
                    ",\"EME_n0/mq/ppmco2\":"+ jsonValue(sensores.ppmCO2) +
                    ",\"EME_n0/yl/lluv\":"+ jsonValue(-1) +
                    ",\"EME_n0/viento/vel\":"+ jsonValue(sensores.vientoVel) +
                    ",\"EME_n0/viento/dir\":"+ jsonValue(sensores.vientoDir) +
                    "}";

  Serial.println("📤 Datos a enviar:");
  Serial.println(postData);
  WebSerial.println(postData);

  if (client.connect(SERVIDOR_ETEC, 443)) {
    Serial.println("Conectado al servidor!");
    WebSerial.println("Conectado al servidor!");

    client.println("POST " apiendpoint " HTTP/1.1");
    client.print("Host: "); client.println(SERVIDOR_ETEC);
    client.println("Content-Type: application/json");
    client.print("Content-Length: "); client.println(postData.length());
    client.println(); client.println(postData);

    while (client.connected()) {
      if (client.readStringUntil('\n') == "\r") break;
    }

    String response = client.readString();
    Serial.println("📥 Respuesta del servidor:");
    Serial.println(response);
    WebSerial.println(response);

    client.stop();
    digitalWrite(ledverde, LOW);
    for (int i = 0; i < 3; i++) {
      digitalWrite(ledverde, HIGH); delay(100);
      digitalWrite(ledverde, LOW);  delay(100);
    }
    digitalWrite(ledverde, HIGH);
  } else {
    Serial.println("❌ No se pudo conectar al servidor.");
    WebSerial.println("❌ No se pudo conectar al servidor.");
  }
}

void setup() {
  Serial.begin(115200);
  pinMode(PIN_GROUND_1, OUTPUT);
  pinMode(PIN_GROUND_2, OUTPUT);
  pinMode(ledverde, OUTPUT);
  digitalWrite(PIN_GROUND_1, HIGH);
  digitalWrite(PIN_GROUND_2, HIGH);

  sensores.begin();
  delay(2000);

  #ifdef USE_PANTALLA
    pantalla.begin();
    pantalla.mostrarInicio();
  #endif

  conectarWiFi();

  WebSerial.begin(&server);
  WebSerial.println("🌐 WebSerial activo. http://<IP>:2020/webserial");
  server.begin();

  #ifdef ota
    ArduinoOTA.setHostname(hostdom);
    ArduinoOTA.begin();
  #endif
  #ifdef WEBAPP
    webapp.begin();
  #endif
}

void loop() {
  #ifdef ota
    ArduinoOTA.handle();
  #endif

  if (WiFi.getMode() == WIFI_AP) {
    handleCaptivePortal();
    delay(10);
    return;
  }

  enviarDatos();

  Serial.println("⏳ Esperando 15 minutos...");
  WebSerial.println("⏳ Esperando 15 minutos...");

  for (int i = 0; i < 900; i++) {
    #ifdef ota
      ArduinoOTA.handle();
    #endif

    if (!WiFi.isConnected()) {
      Serial.println("❌ Desconectado.");
      WebSerial.println("❌ Desconectado.");
      digitalWrite(ledverde, LOW);
      conectarWiFi();
    }

    #ifdef USE_PANTALLA
      if (millis() - tiempoUltimaPantalla > 4000) {
        pantalla.mostrarPantallaCiclo(indicePantalla, sensores);
        indicePantalla = (indicePantalla + 1) % 2;
        tiempoUltimaPantalla = millis();
      }
    #endif

    delay(1000);
  }
}

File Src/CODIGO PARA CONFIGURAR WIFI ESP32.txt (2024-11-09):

#include <WiFi.h>
#include <Preferences.h>
#include <WebServer.h>

// Creamos un objeto Preferences para manejar la configuración en la memoria flash
Preferences preferences;

// Credenciales WiFi predeterminadas (se usarán si no hay nada guardado en las preferencias)
const char* defaultSSID = "TuSSIDPredeterminado";
const char* defaultPassword = "TuContraseñaPredeterminada";

// Creamos una instancia del servidor web en el puerto 80
WebServer server(80);

// Declaración de funciones
void setupAP();
void handleRoot();
void handleSave();
bool connectToWiFi();
void clearPreferences();

void setup() {
  // Iniciamos la comunicación serial para depuración
  Serial.begin(115200);

  // Iniciamos las preferencias en modo lectura/escritura
  preferences.begin("wifi", false);

  // Ofrecemos la opción de borrar las preferencias al inicio
  Serial.println("Presiona 'C' en los próximos 5 segundos para borrar las preferencias...");
  unsigned long startTime = millis();
  while (millis() - startTime < 5000) {
    if (Serial.available() && Serial.read() == 'C') {
      clearPreferences();
      Serial.println("Preferencias borradas. Reiniciando...");
      delay(1000);
      ESP.restart();
    }
  }

  // Intentamos conectarnos al WiFi
  if (!connectToWiFi()) {
    // Si la conexión falla, configuramos el modo punto de acceso
    setupAP();
  }
}

void loop() {
  // Si estamos en modo punto de acceso, atendemos las peticiones web
  if (WiFi.getMode() == WIFI_AP) {
    server.handleClient();
  }
  // Aquí puedes añadir más código para tu aplicación principal
}

bool connectToWiFi() {
  // Leemos las credenciales WiFi de las preferencias
  String ssid = preferences.getString("ssid", defaultSSID);
  String password = preferences.getString("password", defaultPassword);

  Serial.println("Intentando conectar a: " + ssid);

  // Intentamos conectarnos al WiFi
  WiFi.begin(ssid.c_str(), password.c_str());

  // Esperamos hasta 10 segundos por la conexión
  for (int i = 0; i < 20; i++) {
    if (WiFi.status() == WL_CONNECTED) {
      Serial.println("Conectado a WiFi");
      Serial.println("Dirección IP: " + WiFi.localIP().toString());
      return true;
    }
    delay(500);
    Serial.print(".");
  }

  Serial.println("Fallo en la conexión WiFi");
  return false;
}

void setupAP() {
  // Configuramos el ESP32 como punto de acceso
  WiFi.mode(WIFI_AP);
  WiFi.softAP("ESP32_Config", "password");

  // Configuramos las rutas del servidor web
  server.on("/", handleRoot);
  server.on("/save", handleSave);
  server.begin();

  Serial.println("Modo punto de acceso iniciado");
  Serial.println("SSID: ESP32_Config");
  Serial.println("Password: password");
  Serial.println("Dirección IP: " + WiFi.softAPIP().toString());
}

void handleRoot() {
  String html = "<!DOCTYPE html><html lang='es'>"
                "<head>"
                "<meta name='viewport' content='width=device-width, initial-scale=1'>"
                "<title>Configuraci&oacute;n WiFi</title>"
                "<style>"
                "body{font-family:system-ui,-apple-system,BlinkMacSystemFont,'Segoe UI',Roboto,sans-serif;color:#1d1d1f;background-color:#f5f5f7;margin:0;padding:20px;display:flex;align-items:center;justify-content:center;min-height:100vh}"
                ".container{background-color:#fff;padding:30px;border-radius:12px;box-shadow:0 4px 6px rgba(0,0,0,0.1);max-width:300px;width:100%}"
                "h1{font-size:24px;text-align:center;margin-bottom:20px;color:#1d1d1f}"
                "form{display:flex;flex-direction:column}"
                "input{width:100%;padding:10px;margin-bottom:15px;border:1px solid #d2d2d7;border-radius:6px;font-size:14px}"
                "input[type='submit']{background-color:#0071e3;color:white;border:none;font-weight:bold;cursor:pointer}"
                "input[type='submit']:hover{background-color:#0077ed}"
                "</style>"
                "</head>"
                "<body>"
                "<div class='container'>"
                "<h1>EMM ETEC</h1>"
                "<h1>Configuraci&oacute;n WiFi</h1>"
                "<form action='/save' method='post'>"
                "<input type='text' name='ssid' placeholder='Nombre de la red (SSID)' required>"
                "<input type='password' name='password' placeholder='Contrase&ntilde;a' required>"
                "<input type='submit' value='Guardar'>"
                "</form>"
                "</div>"
                "</body>"
                "</html>";
  server.send(200, "text/html", html);
}
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

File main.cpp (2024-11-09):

#include <Arduino.h>
#include <WiFi.h>

#include <PubSubClient.h>
#include <WiFiClientSecure.h>

#include "../lib/LeerSensores.h"
#include "../lib/config.h"
#include "../lib/FormWiFi.h"
#include "esp_sleep.h"

char mensaje[80];

WiFiClient esp_EME;
LeerSensoresControlador controlador;
FormularioWiFi configurador_red;

#define ssid RED_SSID_WIFI
#define pass PASSWORD_WIFI

// URL del servidor con HTTPS (asegúrate que el endpoint de Node-RED no incluya /admin)
const char* serverName = "https://emetec.wetec.um.edu.ar/weather";

// Crear cliente seguro para HTTPS
WiFiClientSecure client;

// Si estás en un entorno de pruebas y no te importa la verificación del certificado:
//client.setInsecure();

#define uS_TO_S_FACTOR 1000000  // Conversión de segundos a microsegundos
#define TIME_TO_SLEEP_15_MIN  15 * 60  // Tiempo en segundos (15 minutos)
#define TIME_TO_SLEEP_5_SEG  5   // Tiempo en segundos (5seg
#define TIME_TO_SLEEP_2_MIN  2 * 60   // Tiempo en segundos (2min)

void envioMQTT();

void setupWifi()
{
  delay(100);
  Serial.print("\nConectando a ");
  Serial.println(ssid);
  WiFi.begin(ssid, pass);

  while (WiFi.status() != WL_CONNECTED)
  {
    delay(200);
    Serial.print(".-");
  }

  Serial.print("\nConectado a la red: ");
  Serial.println(ssid);
  Serial.print("\nCon la siguiente IP: ");
  Serial.println(WiFi.localIP());
}

void reconectar()
{
  Serial.print("\nConectando al broker: ");
  Serial.println(broker);
  while (!client.connected())
  {
    if (client.connect("EME"))
    {
      Serial.print("\nConectado al broker: ");
      Serial.println(broker);
      client.subscribe(chau);
    }
    else
    {
      Serial.print("Error de conexión, rc=");
      Serial.print(client.state());
      Serial.println(".-");
      delay(1000);
    }
  }
}

void callback(char *topic, byte *payload, unsigned int length)
{
  Serial.print("Mensaje recibido: ");
  Serial.println(topic);
  for (unsigned int i = 0; i < length; i++)
  {
    Serial.print((char)payload[i]);
  }
  Serial.println();
}

unsigned long delayTime;
void setup()
{
  // //****Para ESP8266****/
  // // ESP.deepSleep(15*60*1000000);    // DEEP sleep 15 minutos
  // // ESP.deepSleep(5 * 1000000); // DEEP sleep de 5 segundos
  // //****Para ESP32*****/
  // // Configurar el temporizador RTC para que despierte el ESP32 después de TIME_TO_SLEEP segundos
  // // esp_sleep_enable_timer_wakeup(TIME_TO_SLEEP_15_MIN * uS_TO_S_FACTOR);
  // esp_sleep_enable_timer_wakeup(TIME_TO_SLEEP_5_SEG * uS_TO_S_FACTOR);

    // ++bootCount;
    // Serial.printf("Boot number: %d\n", bootCount);

    // print_wakeup_reason();


  Serial.begin(115200);
  String thisBoard = ARDUINO_BOARD;
  Serial.println(thisBoard);




  //  Inicializar controlador de sensores
  controlador.initControlador(BMP_TYPE_180);

  //  Inicializar conexión a la red
  setupWifi();
  client.setServer(broker, 1883);
  client.setCallback(callback);

  // envioMQTT();

  // Serial.print("Entrando a modo Deep Sleep\n");
  // esp_deep_sleep_start();
}

void loop()
{
  envioMQTT();
  delay(2 * 60 * 1000);
  //delay(TIME_TO_SLEEP_5_SEG * 1000);
}


void envioMQTT(){
//  Reconectar si se ha desconectado del Broker
  if (!client.connected())
  {
    reconectar();
  }
  client.loop();

  //  Declaración de variables de lectura para sensores tomando cómo estructura de datos la de la clase LeerSensoresControlador
  LeerSensoresControlador::datosBMP bmpData;
  LeerSensoresControlador::datosDHT dhtData;
  LeerSensoresControlador::datosMQ mqData;
  float bh1750Data;

  //  Lectura y asignación de párametros de los sensores
  dhtData = controlador.leerDHT();
  bmpData = controlador.leerBMP();
  bh1750Data = controlador.leerBH();
  mqData = controlador.leerMQ(dhtData.temperatura, dhtData.humedadRelativa);
  // mqData = controlador.leerMQ();

  bool local = false;
  // bool local = true;

  if (!local){
    // Publicar temperatura ETec_broker
    snprintf(mensaje, 20, "%.2f °C", dhtData.temperatura);
    client.publish(TOPIC_DHT_TEMP, mensaje);
    // Publicar humedad ETec_broker
    snprintf(mensaje, 20, "%.2f %%HR", dhtData.humedadRelativa);
    client.publish(TOPIC_DHT_HUM, mensaje);
    // Publicar sensación térmica ETec_broker
    snprintf(mensaje, 20, "%.2f °C", dhtData.sensacionTermica);
    client.publish(TOPIC_DHT_SENST, mensaje);

    // Publicar temperatura bmp ETec_broker
    snprintf(mensaje, 20, "%.2f °C", bmpData.temperatura);
    client.publish(TOPIC_BMP_TEMP, mensaje);
    // Publicar presion ETec_broker
    snprintf(mensaje, 20, "%.2f hPa", bmpData.presionAbsoluta);
    client.publish(TOPIC_BMP_PRES, mensaje);
    // Publicar altitud ETec_broker
    snprintf(mensaje, 20, "%.2f m", bmpData.altitud);
    client.publish(TOPIC_BMP_ALT, mensaje);
    // Publicar presion a nivel del mar ETec_broker
    snprintf(mensaje, 20, "%.2f hPa", bmpData.presionAlNivelDelMar);
    client.publish(TOPIC_BMP_PRESNM, mensaje);

    // Publicar luz ETec_broker
    snprintf(mensaje, 20, "%.2f lm", bh1750Data);
    client.publish(TOPIC_BH_LUZ, mensaje);

    // Publicar ppmCO2 ETec_broker
    snprintf(mensaje, 20, "%.2f ppmCO2", mqData.ppmCO2);
    client.publish(TOPIC_MQ_PPMCO2, mensaje);

    // Publicar velocidad del Viento ETec_broker
    snprintf(mensaje, 20, "Proximamente");
    client.publish(TOPIC_VIENTO_VELOCIDAD, mensaje);
    // Publicar dirección del viento ETec_broker
    snprintf(mensaje, 20, "Proximamente");
    client.publish(TOPIC_VIENTO_DIRECCION, mensaje);

    // Publicar lluvia ETec_broker
    snprintf(mensaje, 20, "Proximamente");
    client.publish(TOPIC_YL_LLUVIA, mensaje);
  } else {
      // Publicar datos del BMP180
    snprintf(mensaje, 75,
            "estado:OK temperatura:%.2f presAbs:%.2f presNivlMar:%.2f altit:%.2f",
            // bmpData.estado,
            bmpData.temperatura,
            bmpData.presionAbsoluta,
            bmpData.presionAlNivelDelMar,
            bmpData.altitud);
    client.publish(senBMP180, mensaje);

    // Publicar datos del BH1750
    snprintf(mensaje, 20, "Lux:%.2f", bh1750Data);
    client.publish(senBH1750, mensaje);

    // Publicar datos del DHT11
    snprintf(mensaje, 40, "hum:%.2f temp:%.2f sensacionTerm:%.2f",
            // dhtData.estado,
            dhtData.humedadRelativa,
            dhtData.temperatura,
            dhtData.sensacionTermica);
    client.publish(senDHT11, mensaje);

    // Publicar datos del MQ135
    snprintf(mensaje, 75, "rzero:%.2f correctRZero:%.2f res:%.2f ppmCO2:%.2f ppmCorreg:%.2f",
            mqData.rzero,
            mqData.zeroCorregido,
            mqData.resistencia,
            mqData.ppmCO2,
            mqData.ppmCorregidas);
    client.publish(senMQ135, mensaje);
  }
}

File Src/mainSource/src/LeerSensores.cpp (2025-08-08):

#include "Arduino.h"
#include "../lib/LeerSensores.h"

#ifdef USE_DHT
  #include <DHT.h>
  #define DHTTYPE DHT22
#endif

#ifdef USE_BH_SENSOR
  #include <BH1750.h>
#endif

#ifdef USE_ANEMOMETER
  volatile unsigned long anemometerPulseCount = 0;

  void IRAM_ATTR anemometerISR() {
    anemometerPulseCount++;
  }
#endif

// Constructor
LeerSensores::LeerSensores()
#ifdef USE_DHT
  : dht(DHT_PIN, DHTTYPE)
#endif
{
  tempDHT = humDHT = sensDHT = 0;
  tempBMP = presBMP = altBMP = presNMBMP = -1;
  bh1750 = 0;
  ppmCO2 = 0;
  lluviaPosibilidad = 0;
  vientoVel = 0;
  vientoDir = 0;
}

void LeerSensores::begin() {
  Serial.println("---- Estado de Sensores ----");

#if defined(USE_BMP680)
  Serial.println("BMP680: ACTIVADO");
  if (!bmp680.begin()) {
    Serial.println("❌ Error al iniciar BMP680!");
  } else {
    Serial.println("✅ BMP680 listo");
  }

#elif defined(USE_BMP280)
  Serial.println("BMP280: ACTIVADO");
  if (!bmp280.begin(0x76)) {
    Serial.println("❌ Error al iniciar BMP280!");
  } else {
    Serial.println("✅ BMP280 listo");
  }
#else
  Serial.println("BMPs: DESACTIVADO");
#endif

#ifdef USE_DHT
  Serial.println("DHT: ACTIVADO");
  dht.begin();
#else
  Serial.println("DHT: DESACTIVADO");
#endif

#ifdef USE_BH_SENSOR
  Serial.println("BH1750: ACTIVADO");
  if (!lightMeter.begin()) {
    Serial.println("❌ Error al iniciar BH1750!");
  }
#else
  Serial.println("BH1750: DESACTIVADO");
#endif

#ifdef USE_ANEMOMETER
  Serial.println("Anemómetro: ACTIVADO");
  pinMode(PIN_ANEMOMETER, INPUT_PULLUP);
  attachInterrupt(digitalPinToInterrupt(PIN_ANEMOMETER), anemometerISR, FALLING);
#else
  Serial.println("Anemómetro: DESACTIVADO");
#endif

#ifdef USE_HOJA_MOJADA
  Serial.println("Hoja Mojada: ACTIVADO");
  pinMode(HOJA_MOJADA_PIN, INPUT);
#else
  Serial.println("Hoja Mojada: DESACTIVADO");
#endif

#ifdef USE_MQ_SENSOR
  Serial.println("MQ Sensor (MQ135): ACTIVADO");
#else
  Serial.println("MQ Sensor (MQ135): DESACTIVADO");
#endif

#ifdef USE_VELETA
  Serial.println("Velocímetro (VELETA): ACTIVADO");
#else
  Serial.println("Velocímetro (VELETA): DESACTIVADO");
#endif

  Serial.println("---- Fin Estado de Sensores ----");
}

void LeerSensores::leerTodos() {

#if defined(USE_BMP680)

  if (bmp680.performReading()) {
    tempDHT = bmp680.temperature;
    humDHT = bmp680.humidity;
    sensDHT = 0;

    tempBMP = bmp680.temperature;
    presBMP = bmp680.pressure / 100.0;
    altBMP = bmp680.readAltitude(1013.25);
    presNMBMP = presBMP / pow(1.0 - (750.0 / 44330.0), 5.255);

    ppmCO2 = bmp680.gas_resistance / 1000.0;  // Valor estimado
  } else {
    Serial.println("❌ Falló la lectura del BMP680");
    tempDHT = humDHT = sensDHT = -1;
    tempBMP = presBMP = altBMP = presNMBMP = -1;
    ppmCO2 = -1;
  }

#else

  #ifdef USE_DHT
    float t = dht.readTemperature();
    float h = dht.readHumidity();
    float st = dht.computeHeatIndex(t, h, false);
    if (isnan(t) || isnan(h)) {
      Serial.println("Error leyendo DHT!");
      tempDHT = humDHT = -100;
      sensDHT = 0;
    } else {
      tempDHT = t;
      humDHT = h;
      sensDHT = st;
    }
  #else
    tempDHT = humDHT = -1;
    sensDHT = 0;
  #endif

  #ifdef USE_BMP280
    tempBMP = bmp280.readTemperature();
    presBMP = bmp280.readPressure() / 100.0;
    altBMP = bmp280.readAltitude(1013.25);
    presNMBMP = presBMP / pow(1.0 - (750.0 / 44330.0), 5.255);
  #else
    tempBMP = presBMP = altBMP = presNMBMP = -1;
  #endif

  #ifdef USE_MQ_SENSOR
    int mqValue = analogRead(PIN_MQ135);
    ppmCO2 = (mqValue / 4095.0) * 5000.0;
  #else
    ppmCO2 = -1;
  #endif

#endif // USE_BMP680

  #ifdef USE_BH_SENSOR
    bh1750 = lightMeter.readLightLevel();
  #else
    bh1750 = -1;
  #endif

  #ifdef USE_ANEMOMETER
    noInterrupts();
    unsigned long pulseCount = anemometerPulseCount;
    anemometerPulseCount = 0;
    interrupts();
    float windSpeedKmh = (pulseCount * 2.4);
    vientoVel = windSpeedKmh / 3.6;
  #else
    vientoVel = -1;
  #endif

  #ifdef USE_VELETA
    int analogVal = analogRead(VELETA_Y);
    vientoDir = map(analogVal, 0, 4095, 0, 360);
  #else
    vientoDir = -1;
  #endif

  #ifdef USE_HOJA_MOJADA
    lluviaPosibilidad = digitalRead(HOJA_MOJADA_PIN);
  #else
    lluviaPosibilidad = 0;
  #endif

  #ifdef pantallita
    serial.print("Temperatura DHT: ");
  #endif
}

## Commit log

2024-03-07 Se añadió nodejs y se añadio un ejemplar de conexion a una db local (mysql)
2024-04-22 Se agregó diseño3D y PCB v0.1
    [BaseVeleta v1.f3d, BaseVeleta v1.stl, EME.kicad_pcb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]
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2024-05-07 se agregaron ejemplos de los sensores y actualizo la PCB
    [EME.kicad_pcb, EME.kicad_sch]
2024-05-10 Se movió la carpeta de ejemplos para mejor funcionamiento de PIO. Se añadieron/modificaron ejemplos de bmp180, bh170, dht22
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2024-06-17 Se armó diseño de PCB y se decoró esquemático
    [EME.kicad_pcb, EME.kicad_sch]
2024-06-17 Se avanzó con los programas de ejemplo de Anemómetro y Veleta, falta verificarlos en simulador
2024-06-17 se han agregado los readmes a cada carpeta relevante, además de fotos de lo de kicad
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2024-08-04 se agregó código de mainSource que es el prototipo funcional v0.2 de la EME
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2024-08-04 se espejó y adapto la librería LeerSensores que funciona en la EMM, queda revisar por 3ro
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2024-08-07 se actualizó el envío de datos por mqtt de forma más ordenada
2024-08-07 se arregló el envío de data que estaba mal las unidades
    [LeerSensores.cpp, main.cpp]
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2024-08-11 Se corrigieron errores de la web.
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2024-08-15 Changes to be committed: new file: .gitignore deleted: Src/main.c modified: Src/mainSource/platformio.ini new file: Web/Node-Red/Flow_releaseV0(13-08-24).json modified: Web/graphics.js new file: pcb/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
2024-09-03 Se añadió el codigo de ejemplo RTC. Se empezó con lo solicitado en la parte web.
2024-09-29 Refactorizar código para agregar funcionalidad de selección de categoría en la parte web
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2024-10-02 Se corrigió el tiempo que demora en enviar los datos.
    [main.cpp]
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2024-10-23 ffw4420 9fsr ed
    [EME.kicad_pcb]
2024-10-27 se actualizó la PCB
    [EME.kicad_pcb, EME.kicad_sch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]
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2024-11-01 Se corrigió la visualización del último dato
2024-11-02 Cambios en el dropdown: Se le añadio Test a la pestaña Datos, y se configuró una cookie
2024-11-02 Añadido URLs de API para la gestión de datos en el archivo app.js
2024-11-02 Añadidas funciones para gestionar cookies y descargar datos en XLSX según la selección del dropdown
2024-11-02 Añadidas variables para las URLs de las APIs en excel.js y actualizada la función de descarga para usar estas variables según la categoría seleccionada
2024-11-02 Actualizada la documentación del README.md para incluir descripciones detalladas del Dashboard. Se mejoró la interfaz de usuario en index.html añadiendo estilo de cursor a las imágenes de perfil. Se 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
2024-11-02 Añadido test http a través. Se incluye la configuración de conexión Wi-Fi y se aumenta el tamaño del buffer para el mensaje JSON. Se agrega la dependencia HTTPClient en platformio.ini.
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2024-11-09 update main
    [CODIGO PARA CONFIGURAR WIFI ESP32.txt, EME.kicad_pcb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]
2024-11-10 se agregó función de encendido de MOSFET, posibilidad de elección entre diversos DHT's y se agregaron etiquetas de funciones
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2024-11-14 Corregidas descripciones de estudiantes en index.html para incluir "de la ETec" y añadido nuevo integrante al equipo.
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2024-11-19 Se actualizó PCB y se agregó funcionalidad de sensor lluvia, veleta y anemómetro
    [EME.kicad_pcb]
2024-11-19 se agregó funcionalidad correcta del anemometro
    [LeerSensores.cpp]
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2024-12-07 Agregar opción 'emm3' en la función de descarga de datos y definir la URL correspondiente
2024-12-07 Actualizar URL de API y optimizar la obtención de datos en gráficos; agregar opción 'emm3' en el dropdown de nodos meteorológicos
2024-12-07 Actualizar la inclusión de scripts en graphs.html para usar la nueva URL de graphics.js
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2025-02-26 Añadir soporte para el nodo "Colegio San Jorge" en la selección de categorías y actualizar las URLs de la API en excel.js
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2025-02-28 Nueva versión de la PCB, se saca a parte veleta y anemómetro en placas aparte con los sensores
    [EME.kicad_pcb, EME.kicad_sch]
2025-02-28 Agregada carpetas para PCBs
    [EME.kicad_pcb, EME.kicad_sch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]
2025-03-01 Actualizar la configuración de PlatformIO y mejorar el controlador WiFi eliminando código redundante y ajustando la implementación del servidor web cautivo. Deepsleep mediante post.
2025-03-02 Actualizar la configuración de PlatformIO y eliminar código redundante en LeerSensores. Agregar funcionalidad para eliminar credenciales WiFi.
2025-03-02 se readaptaron y revisaron las PCBs, listas para imprimir
    [EME.kicad_pcb, EME.kicad_sch, Placa ANEMOMETRO.kicad_pcb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]
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2025-04-04 Se agregó la modificación del MQ135 a 5v con divisor resistivo; además de cambio del DHT del pin 12; también se modificaron los pines de conexión
    [EME.kicad_pcb, EME.kicad_sch, Placa ANEMOMETRO.kicad_pcb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]
2025-04-13 Agregar archivos de configuración y nuevas páginas HTML, eliminar archivos innecesarios y actualizar .gitignore
    [datos.xlsx]
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2025-04-13 Corregir la ruta del archivo CSS en datos.html para asegurar la carga correcta del estilo
2025-04-13 Actualizar rutas de archivos CSS y JS en about_us.html y datos.html para asegurar la carga correcta de los estilos y scripts
2025-04-13 Actualizar rutas de archivos CSS y JS en index.html para asegurar la carga correcta de los estilos y scripts
2025-04-14 Eliminar archivo datos.xlsx y agregar funcionalidad para verificar el estado del nodo en datos.html y back.js
    [datos.xlsx]
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2025-04-23 pcb review
    [estacionMeteorologica v3.stl]
2025-04-24 Agregar cálculo del índice de calor en la lectura de sensores y mejorar la conexión HTTP en el cliente
    [EME.kicad_pcb]
2025-04-25 revisión de pcb
    [EME.kicad_pcb, EME.kicad_sch]
2025-04-25 se arregló el funcionamiento de los mosfet y la lectura del MQ135, falta ver porque se no deja resetearse
    [LeerSensores.cpp, main.cpp]
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2025-05-20 "se modificó conexión del DHT22 a otro pin, se agregó jumper G-g1 y g2, también conectores para extraer alimentación"
    [EME.kicad_pcb, EME.kicad_sch]
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2025-06-26 Add PantallaController for LCD display management
    - Created header file pantallacontroller.h to define the PantallaController class with methods for displaying various information on an LCD.
    - Implemented pantallacontroller.cpp to provide functionality for initializing the LCD, displaying welcome messages, sensor readings, WiFi status, and error messages.
    - Added .gitignore to exclude build and configuration files.
    - Introduced extensions.json for VSCode to recommend necessary extensions for the project.
    [LeerSensores.cpp, main.cpp]
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2025-06-30 Add lock file for EME.kicad_pcb to track editing session
    [EME.kicad_pcb]
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
